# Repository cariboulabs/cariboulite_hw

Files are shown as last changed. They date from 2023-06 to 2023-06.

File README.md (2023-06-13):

# CaribouLite
CaribouLite is an affordable, educational, open-source SDR evaluation platform and a HAT for the Raspberry-Pi family of boards (40-pin versions only). It is built for makers, hackers, and researchers and was designed to complement the current SDR (Software Defined Radio) eco-systems offering with a scalable, standalone dual-channel software-defined radio.

<table>
  <tr>
    <td>Open source hardware association certificate</td>
    <td>This project has been certified by OSHWA</td>
  </tr>
</table>

<table>
  <tr>
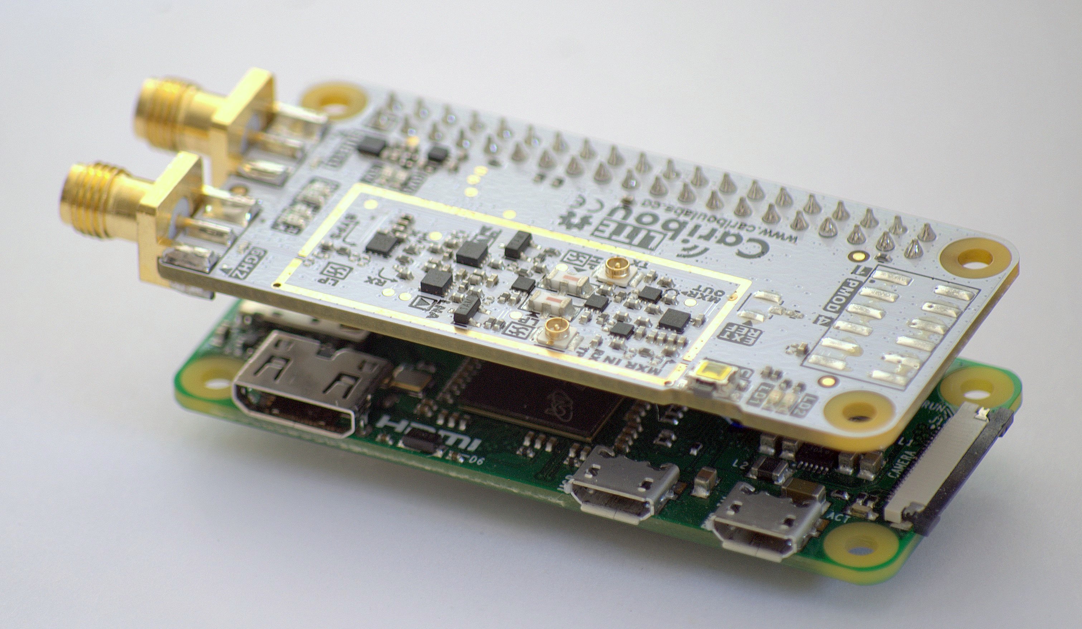
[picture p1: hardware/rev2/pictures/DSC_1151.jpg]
CaribouLite R2
    <td></td>
  </tr>
  <tr>
    <td>CaribouLite R2.5 SDR mounted on a RPI-Zero</td>
  </tr>
</table>

# Getting Started & Installation
Use the following steps to install the CaribouLite on your choice of RPI board
1. Mount the CaribouLite on a **un-powered** RPI device using the 40-pin header.
2. Power the RPI device, wait for it to finish boot sequence.
3. Clone this repository into a local directory of your choise (in this case `~/projects`)
```
mkdir ~/projects
cd ~/projects
git clone https://github.com/cariboulabs/cariboulite
cd cariboulite
```
4. Use the following setup command (**note: don't `sudo` it**):
    ```
    install.sh
    ```

The setup script **requires internet connection** and it follows the following automatic steps:
1. **Dependencies** installation (apt)
2. **Soapy API tools installation** (SoapySDR and SoapyRemote) - only if they are not currently present in the system. Installation from code.
3. **Internal dependencies installation**
   1. Utilities and tools
   2. IIR DSP library
   3. SMI stream device module (kernel object) blob generation
4. **Main software** and SoapyAPI compilation and installation
5. **Raspberry PI configuration** verification. Note - the installer doesn't not actively change the RPI's configuration to fit to CaribouLite. It just checks the `/boot/config.txt` configuration file and raises warning when problem is detected. Then the user shall need to adjust the parameters accordingly.

Note: the user will be requested to enter their password during the installation process.

## Installation Troubleshooting
1. **Modules**: Both the `spi` and `arm-i2c` dtoverlays should be disabled to run CaribouLite properly. The `libcariboulite` doen't use them. It uses direct access to `/dev/mem` to expose these peripherals (through the `pigpio` library).
The interfaces can be disabled (or enabled back whenever needed) by either directly editing the `/dev/config.txt` file or by using the `sudo raspi-config` command. The latter is the preferred choice as it is straight forward, less error prone and it works on all RaspberryPi's OS distributions (including DragonOS).
If the direct editing path has been chosen (`/boot/config.txt`), the following lines
should be commented out:
`#dtparam=spi=on`
`#dtparam=i2c_arm=on`

2. **Kernel headers** - `libcariboulite` loads a custom kernel module (`smi_stream_dev`) during startup. The kernel module sources are location in : **`/software/libcariboulite/caribou_smi/kernel`**. Recompilation of these .ko obejcts is needed whenever software is pulled. This requires currently to have the local host system to have the kernel headers installed. In addition, upgrading the kernel will require recompilation with the updated kernel headers. Once the `smi_stream_dev` is listed inside the main kernel tree, this process will become redundant.

3. **sudo**ing - Currently hardware is accessed through the PIGPIO library. It should be given a root access to control the low level interfaces through the `/dev/mem` device. The relevant part of the software that is concerned in this matter is the "io_utils" sub-module. Once this module is re-designed to access the hardware through the "gpiomem" and "spidev" modules, this restrictions shall be mitigated (by the definitions of `udev` rules).
So currently, sudo'ing is needed whenever CaribouLite is accessed (including sudo'ing python...).

To compile the API library and SoapySDR API from code please click [here](/software/libcariboulite/README.md)

# SMI Interface

Unlike many other HAT projects, CaribouLite utilizes the **SMI** (Secondary Memory Interface) present on all the 40-pin RPI versions. This interface is not thoroughly documented by both Raspberry-Pi documentation and Broadcomm's reference manuals. An amazing work done by [Lean2](https://iosoft.blog/2020/07/16/raspberry-pi-smi/) (code in [git repo](https://github.com/jbentham/rpi)) in hacking this interface has contributed to CaribouLite's technical feasibility. A deeper overview of the interface is provided by G.J. Van Loo, 2017 [Secondary_Memory_Interface.pdf](docs/smi/Secondary%20Memory%20Interface.pdf). The SMI interface allows exchanging up to ~500 Mbit/s (depending on the FPGA, data-bus width, etc.) between the RPI and the HAT, and yet, the results vary between the different versions of RPI. The results further depend on the specific RPI version's DMA speeds.

The SMI interface can be accessed from the user space Linux applications as shown in [Lean2](https://iosoft.blog/2020/07/16/raspberry-pi-smi/), but Broadcomm also provided a neat minimal charachter device interface in the `/dev` directory using the `open`, `close`, `write`, `read`, and `ioctl` system calls. More on this interesting interface in the [designated readme file](software/libcariboulite/src/caribou_smi/index.md). This device driver needs to be loaded using `modprobe`.

More information on this interface can be found [here (HW side)](docs/smi/README.md) and [here (SW side)](software/libcariboulite/src/caribou_smi/README.md).

<table>
  <tr>
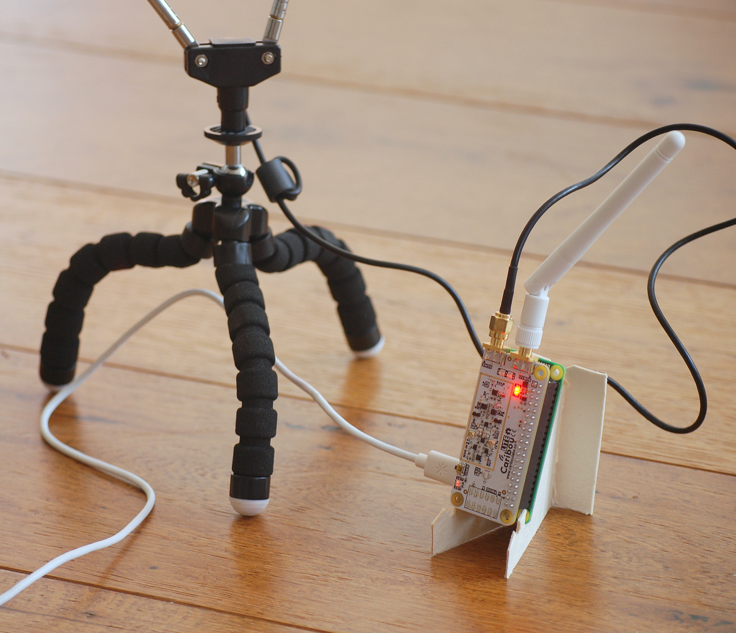
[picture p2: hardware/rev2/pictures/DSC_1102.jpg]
    <td></td>
  </tr>
  <tr>
    <td>Cariboulite /w RPI Zero, two channels occupied</td>
  </tr>
</table>

# Hardware Revisions
The board first prototyping (**Red**) revision ([REV1](hardware/rev1)) has been produced and tested to meet our vision on the board's capabilities. This revision was used to test its RF parts, the digital parts, and to develop its firmware and software support over the RPI.

<table>
  <tr>
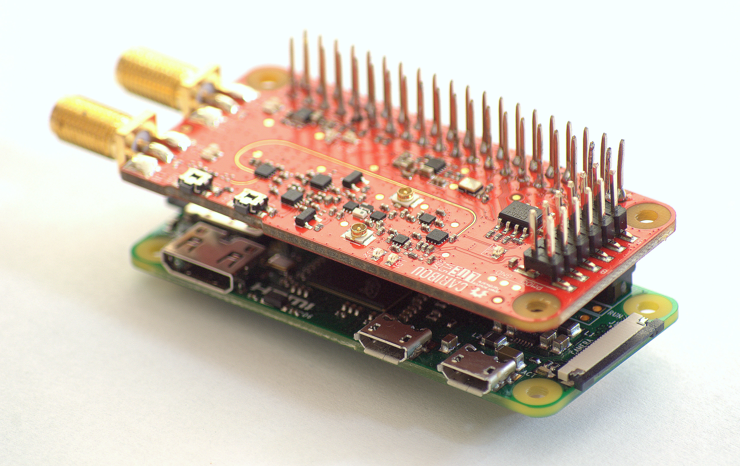
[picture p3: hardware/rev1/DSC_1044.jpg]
CaribouLite R1
    <td></td>
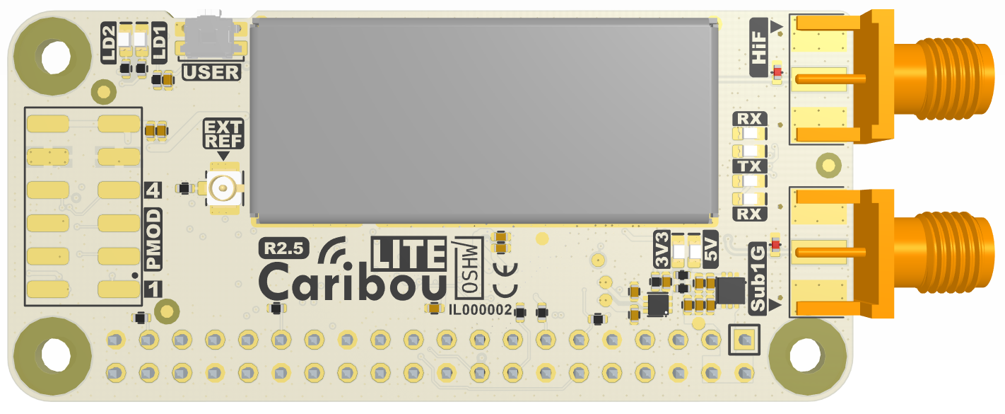
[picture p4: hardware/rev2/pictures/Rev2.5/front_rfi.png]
CaribouLite Connectors
    <td></td>
  </tr>
  <tr>
    <td>CaribouLite Rev1 - the prototype version</td>
    <td>CaribouLite Rev2.5 - Production Revision</td>
  </tr>
</table>

The second revision ([REV2](hardware/rev2)) - **White** - was then designed to further refine the design as described below:
1. Image rejection filtering improvement - U10 and U12 (HPF & LPF) - have been replaced by integrated LTCC filters by MiniCircuits with much better out-of-band rejection than the former ones.
2. Removing FPGA flash - redundant given the fact that the the RPI configures the FPGA in <1sec over SPI. Even if we have a whole library of custom made FPGA firmware files, switching between them is as simple and fast as a single linux command.
3. Board layout improvements and overlays (silkscreen) beautification (including logo).
4. A single system level 3.3V power (while the FPGA still receives 2.5V and 1.2V for its core). A linear regulator (rather than a switching DC-DC) was used to reduce conducted (power and ground) noise levels.
5. Top and bottom EMI sheilding option - the EMI/RFI shield design models are provided in the [3d directory](hardware/rev2/3d/)
6. More detailed changes in the [schematics](hardware/rev2/schematics/cariboulite_r2_sch.PDF).

In summary, in CaribouLite-Rev2.5 PCB design has been thoroughly re-thought to meet its educational needs with performance in mind. The RF path has been annotated with icons to ease the orientation in the schematics sheets, friendly silk writing was added describing system's components by their functionality rather than logical descriptors, and more.

<table>
  <tr>
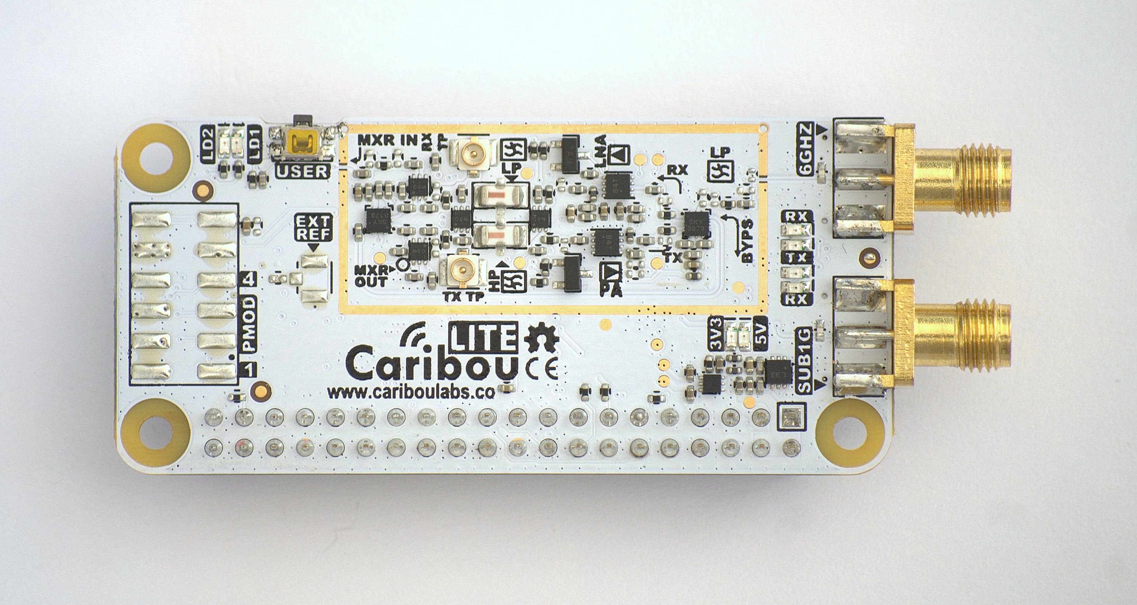
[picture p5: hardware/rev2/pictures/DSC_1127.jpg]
    <td></td>
  </tr>
  <tr>
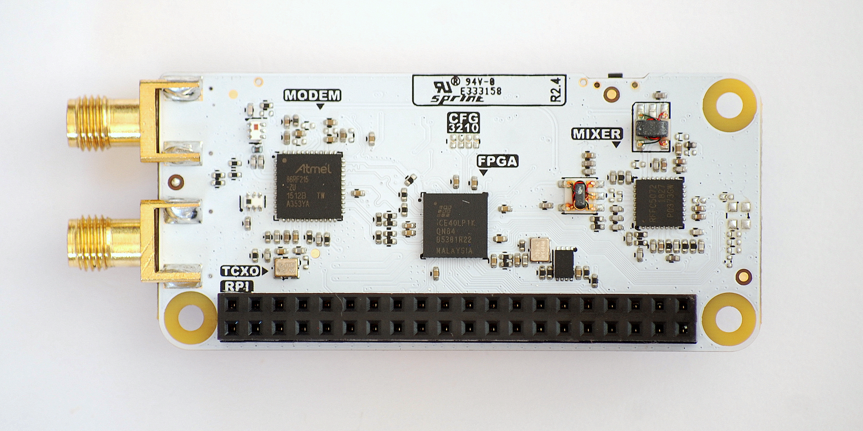
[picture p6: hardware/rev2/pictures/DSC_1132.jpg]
    <td></td>
  </tr>
  <tr>
    <td>Top and Bottom views of CaribouLite <b>Rev2.4</b> (pre-production)</td>
  </tr>
</table>

<table>
  <tr>
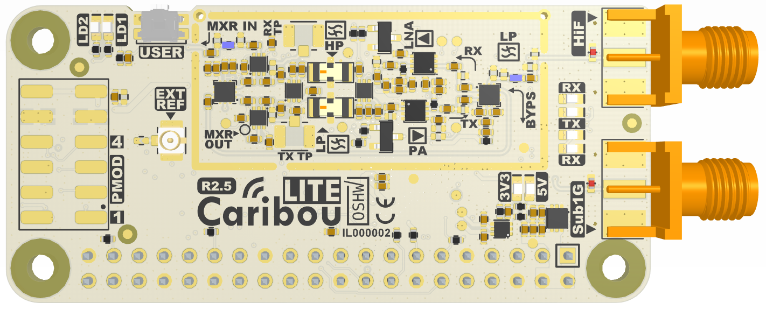
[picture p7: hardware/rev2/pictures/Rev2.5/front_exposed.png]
    <td></td>
    <td>Top View</td>
  </tr>
  <tr>
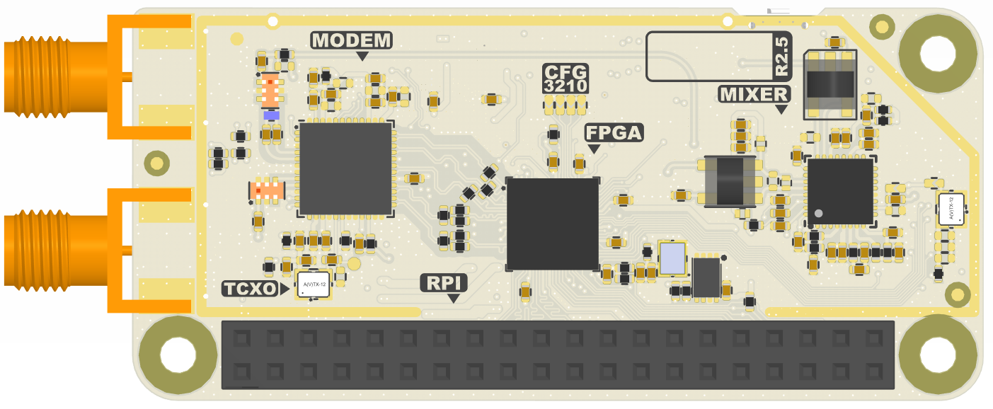
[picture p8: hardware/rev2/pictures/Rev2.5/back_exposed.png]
    <td></td>
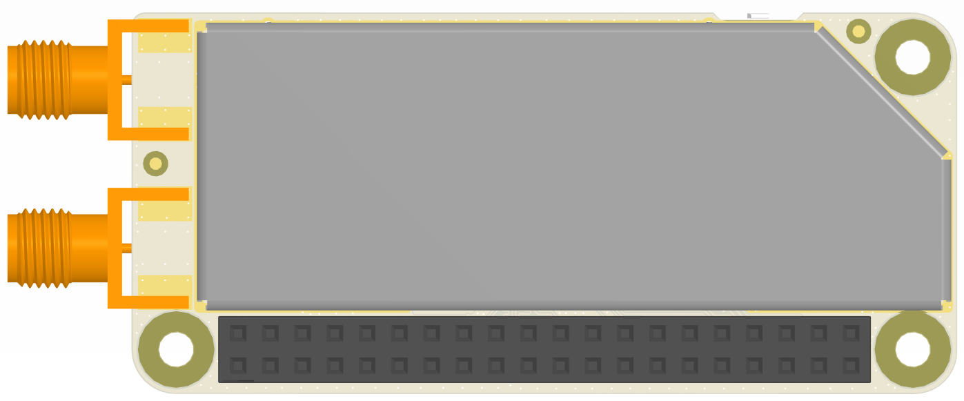
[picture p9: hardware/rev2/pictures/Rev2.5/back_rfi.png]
  <td></td>
  </tr>
  <tr>
    <td>Top and Bottom views of CaribouLite <b>Rev2.5</b></td>
    <td>Top and Bottom views of CaribouLite <b>Rev2.5</b> with EMI/RFI shields</td>
  </tr>
</table>

# Specifications

<B>RF Channels:</B>
- Sub-1GHz: 389.5-510 MHz / 779-1020 MHz
- Wide tuning channel: 30 MHz - 6 GHz (excluding 2398.5-2400 MHz and 2483.5-2485 MHz)

<table>
  <tr>
    <td>spectra</td>
  </tr>
  <tr>
    <td style="text-align:center">Applicable spectra, S1G - sub-1GHz, WB - Wide tuning channel</td>
  </tr>
</table>
<B>Note</B>:
The gaps are defined by the design constraints of the system and may not exist in real-life hardware. Actual modem synthesizer outputs test show wider margins at room temperature than those written in the datatsheet, but, as noted by Microchip, performance may suffer.

<B>FPGA specifications:</B>
- 160 LABs / CLBs
- 1280 Logic Elements / Cells
- 65536 Total RAM bits
- 67 I/Os, Temp: -40-100 degC

<B>Applicable RPI models</B>: RPI_1(B+/A+), RPI_2B, RPI_Zero(Zero/W/WH), RPI_3(B/A+/B+), RPI_4B

Parameter                  |  Sub-1GHz                    | Wide Tuning Channel
---------------------------|------------------------------|------------------------------------------------------------------
Frequency tuner range      | 389.5-510 MHz / 779-1020 MHz | 30 MHz - 6 GHz (excluding 2398.5-2400 MHz and 2483.5-2485 MHz)
Sample rate (ADC / DAC)    | 4 MSPS                       | 4 MSPS
Analog bandwidth (Rx / Tx) | 2.5 MHz                      | 2.5 MHz
Max Transmit power         | 14 dBm                       | >10 dBm @ 30-2400 MHz, >5 dBm @ 2400-6000 MHz
Receive noise figure       | <5 dB                      | <6 dB @ 30-3500 MHz, <8 dB @ 3500-6000 MHz

<B>Note</B>:
(1) Feature comparison table with other SDR devices will be published shortly
(2) Some of the above specifications are simulated rather than tested
(3) Analog bandwidth controlled by the modem
(4) The ISM version of the board doesn't contain the wide-range of frequencies (30-6000 MHz) and contains the native capabilities of the Modem IC.

# Disclaimer
CaribouLite is a test equipment for RF systems. You are responsible for using your CaribouLite legally.

Definitions: THE SUBJECT CONTENT: all files, software, instructions, information, ideas and knowledge located in this git repository.

No Warranty: THE SUBJECT CONTENTS ARE PROVIDED "AS IS" WITHOUT ANY WARRANTY OF ANY KIND, EITHER EXPRESSED, IMPLIED, OR STATUTORY, INCLUDING, BUT NOT LIMITED TO, ANY WARRANTY THAT THE SUBJECT CONTENTS WILL CONFORM TO SPECIFICATIONS, ANY IMPLIED WARRANTIES OF MERCHANTABILITY, FITNESS FOR A PARTICULAR PURPOSE, OR FREEDOM FROM INFRINGEMENT, ANY WARRANTY THAT THE SUBJECT CONTENTS WILL BE ERROR FREE, OR ANY WARRANTY THAT DOCUMENTATION, IF PROVIDED, WILL CONFORM TO THE SUBJECT CONTENTS. FURTHER, THE REPOSITORY OWNERS AND CONTRIBUTORS DISCLAIM ALL WARRANTIES AND LIABILITIES REGARDING THIRD-PARTY SOFTWARE, IF PRESENT IN THE ORIGINAL SOFTWARE, AND DISTRIBUTE IT "AS IS."

Waiver and Indemnity: RECIPIENT AGREES TO WAIVE ANY AND ALL CLAIMS AGAINST THE REPOSITORY OWNERS AND CONTRIBUTORS, THEIR CONTRACTORS AND SUBCONTRACTORS, AS WELL AS ANY PRIOR RECIPIENT. IF RECIPIENT'S USE OF THE SUBJECT CONTENTS RESULTS IN ANY LIABILITIES, DEMANDS, DAMAGES, EXPENSES OR LOSSES ARISING FROM SUCH USE, INCLUDING ANY DAMAGES FROM PRODUCTS BASED ON, OR RESULTING FROM, RECIPIENT'S USE OF THE SUBJECT CONTENTS, RECIPIENT SHALL INDEMNIFY AND HOLD HARMLESS THE REPOSITORY OWNERS AND CONTRIBUTORS, THEIR CONTRACTORS AND SUBCONTRACTORS, AS WELL AS ANY PRIOR RECIPIENT, TO THE EXTENT PERMITTED BY LAW.

# License
<br />This work is licensed under a <a rel="license" href="http://creativecommons.org/licenses/by-sa/4.0/">Creative Commons Attribution-ShareAlike 4.0 International License</a>.

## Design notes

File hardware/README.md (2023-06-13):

# CaribouLite Hardware

## CaribouLite Hardware Revisions

CaribouLite board has two revisions:

1. Rev1: A prototyping revision (the red board).
2. Rev2: Production revision (currently R2.5 is the production-grade version).
   1. Rev2_r2.4: pre-production revision

This documentation shall cover the production-grade board (rev2).

## System Diagram

<table>
  <tr>
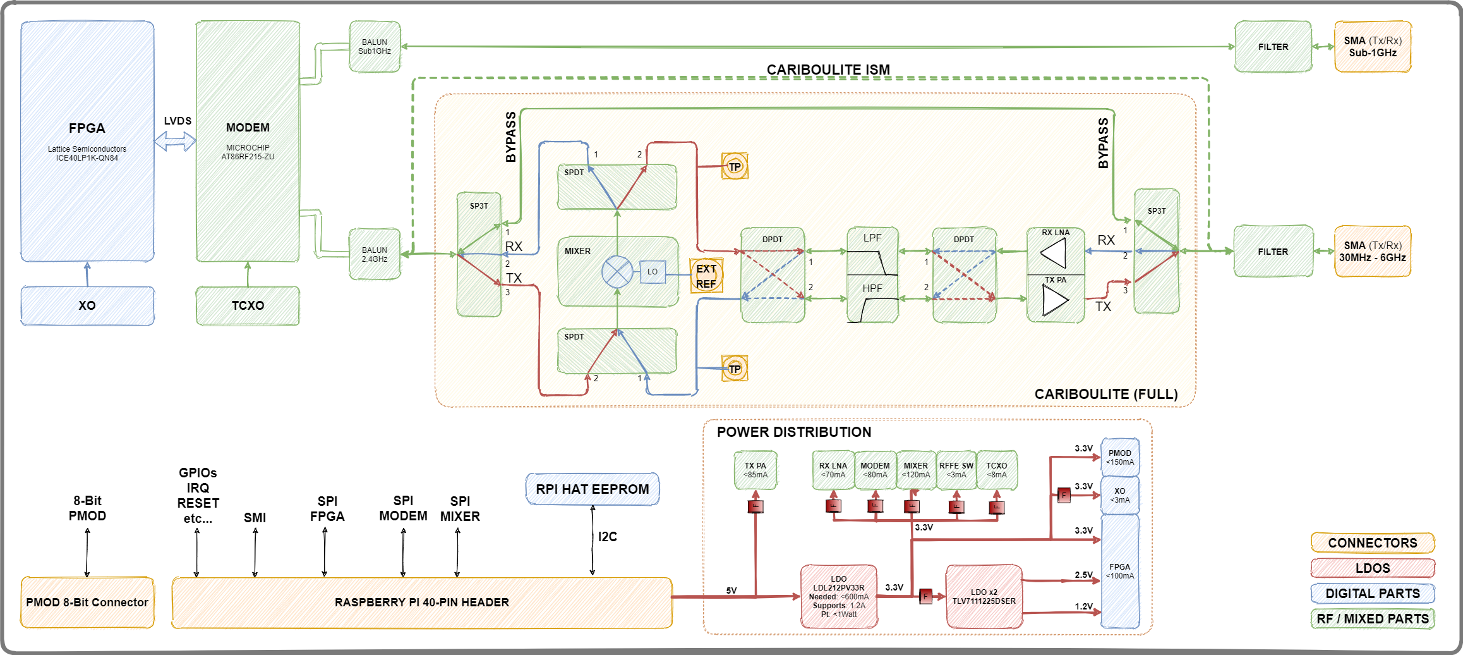
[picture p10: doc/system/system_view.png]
Top View
    <td></td>
  </tr>
  <tr>
    <td>CaribouLite SDR System Diagram</td>
  </tr>
</table>

The **RF chart** in the 6GHz channel was inspired by the **RF front-end of HackRF-One by @greatscottgadgets** (an amazing ground breaking work still relevant today) with a few changes:
1. Usage of DPDTs instead of SPDTs in the filter-bank section. Usage of less switches in general.
2. Using higher attenuation stop-band filtering for a slightly better image rejection.
3. Mixer balun's according according to the requirements of the mixer IC.
4. LNA / PA slight improvements.

Possibilities exist to replace the 6GHz by a other types of components by Qorvo that are pin2pin compatible with the RFFC5072.

### Power Distribution

To simplify the board and its interfacing to the Raspberry Pi computer, all components on board operate with 3.3V. The FPGA further requires also 1.2V and 2.5V voltages. Two LDO components have been used to derive these voltages from the RPI 5V output voltage.

The usage of LDOs provides high level of voltage isolation, low emitted noise, and design simplicity. The downside of such choice it the dissipated heat from the LDOs. This heat is controlled by providing descent heat sinking to the board through the power planes and adjacent metallic elements (i.g. connectors).

The power distribution provides high frequency isolation of the RF components from the digital components (memory, RPI and FPGA) at frequencies lower than 10 MHz. Above 100 MHz additional isolation is provided by using ferrite beads with high impedance (>500 Ohms) at 100MHz. A set of filtering bypass capacitors have been chosen to further suppress noise generated by components on their power lines at mid-range frequencies (10 to 100 MHz) - the set contains 1nF, 100 nF and 4.7uF capacitors bypassing power and data lines effective at the said frequency ranges.

### RPI HAT EEPROM

An I2C EEPROM device is assembled on CaribouLite to support for the requirements of RPI HATs as described in [RPI HAT Requirements](https://github.com/raspberrypi/hats).
Production application helps to perform the EEPROM configuration process (coming soon)

### Clocking

The FPGA is externally clocked by a crystal oscillator of 125MHz located in the bottom side of the board.
Clocking the FPGA from the RPI GPCLK (GPIO4 / GPCLK0 / SMI_SA1) is also possible but not recommanded as it may cause substantial increase in the board EMI. For that reason, the GPCLK option is possible but not used in the mainline hardware version. Hacking the possibility to clock from the RPI is a good idea though.

The MODEM (AT86RF215) is clocked from a 26MHz TCXO (bottom layer). This device provides a stable and low phase noise clock reference to the receivers and transmitters within the IC. The MODEM further outputs a buffered version of the input clock (typically 26MHz, but other possibilities exist as well), to the MIXER input. A capacitor divider circuit adapts the LVCMOS output from the MODEM to the input levels of the MIXER.

The MIXER can also be clocked from a separate dedicated TCXO (not assembled), or an external coherent clock source.
<table>
  <tr>
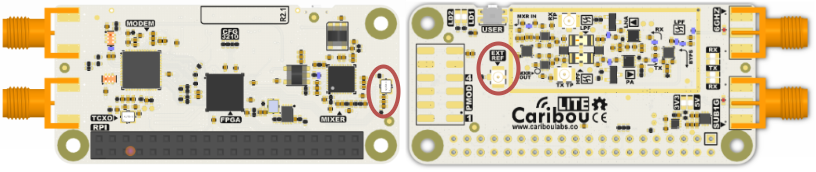
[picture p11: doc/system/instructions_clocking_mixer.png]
    <td></td>
  </tr>
  <tr>
    <td>MIXER clocking options, other than the default MODEM provided reference clock</td>
  </tr>
</table>
To enable the above clocking schemes, the MODEM clock input jumper should be cut, and the appropriate jumpers need to be shorted. Consult the schematics to learn more.

### PMOD Connector

Coming soon:

* Synchronization
* GPS PPS Signaling
* Peripherals
* Maximal current

### FPGA and LVDS

Coming soon - LVDS calculations

### Calibrations & Testing

Coming soon

## License

<br />This work is licensed under a <a rel="license" href="http://creativecommons.org/licenses/by/4.0/">Creative Commons Attribution 4.0 International License</a>.

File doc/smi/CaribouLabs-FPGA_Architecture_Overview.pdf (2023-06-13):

# CaribouLite FPGA / SMI

# - Overview - Architecture - Firmware Software - Firmware top level - SMI I/F

Creative Commons Attribution-ShareAlike 4.0 International License. (http://creativecommons.org/licenses/by-sa/4.0/)

# Portable SDR?

# We wanted to make a portable RF board that connects to an existing compute unit

# >70% of the RF board (the front-end) should be RF components!

RF

# (SDR Front-End)

# A popular Tiny computer (SDR Baseband)

# Some “communication”

# Small and self-contained SDR

# Portable

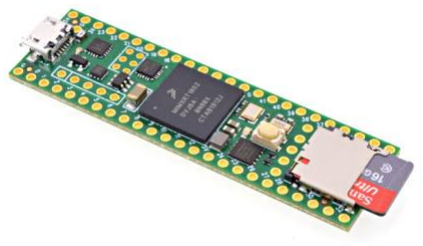
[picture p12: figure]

# SDR?

# The platform problem

# - We want to focus on RF, not Compute - So, which is the best platform?

TEENSY 4.1 | Raspberry Pi | Jetson Nano

# +++ Cheap ++ Popular + NXP-FlexIO

# --- Performance --- No Linux

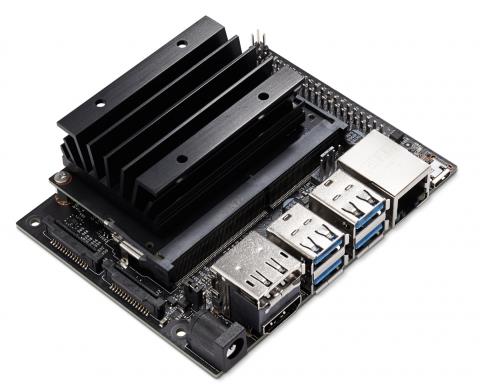
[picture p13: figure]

# +++ Performance ++ Popular

+ AI

# - Expensive -- I/Q Interface?

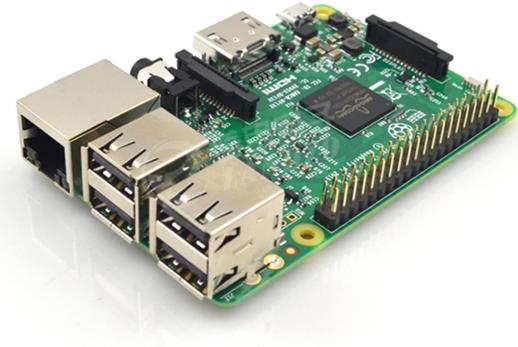
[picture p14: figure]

# ++ Performance +++ Popular (community) +++ Cheap - Affordable

# - I/Q Interface?

# SMI

# Top Structure

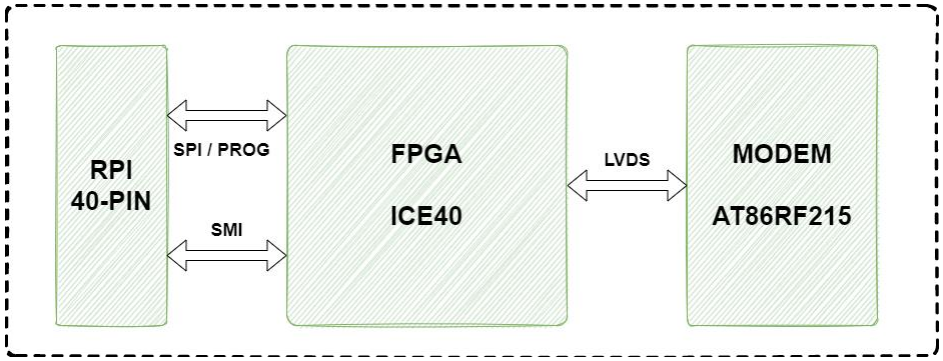
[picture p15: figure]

# - FPGA mediates between LVDS and SMI - SPI – controlling FPGA functionality - FPGA programming – done by RPI (Lattice SPI)

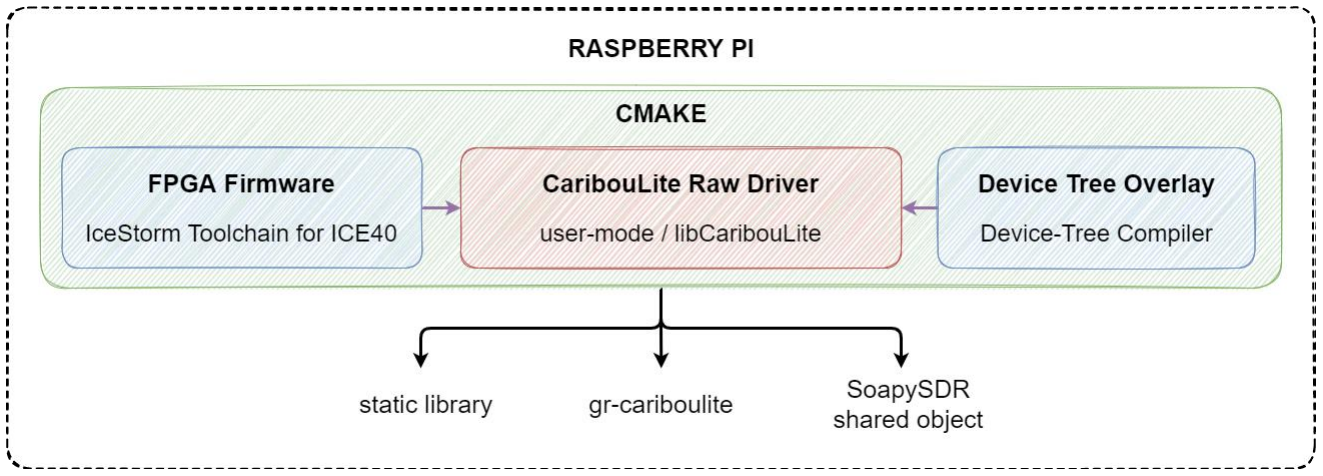
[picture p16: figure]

# Firmware

# Software

# Integration

# - Verilog – Yosys + NextPNR ➔ code blob in C/C++ - Device tree – DTC ➔ code blob in C/C++ - One CMAKE project ➔ SoapySDR, GnuRadio, static-lib

# - All inside Raspberry Pi

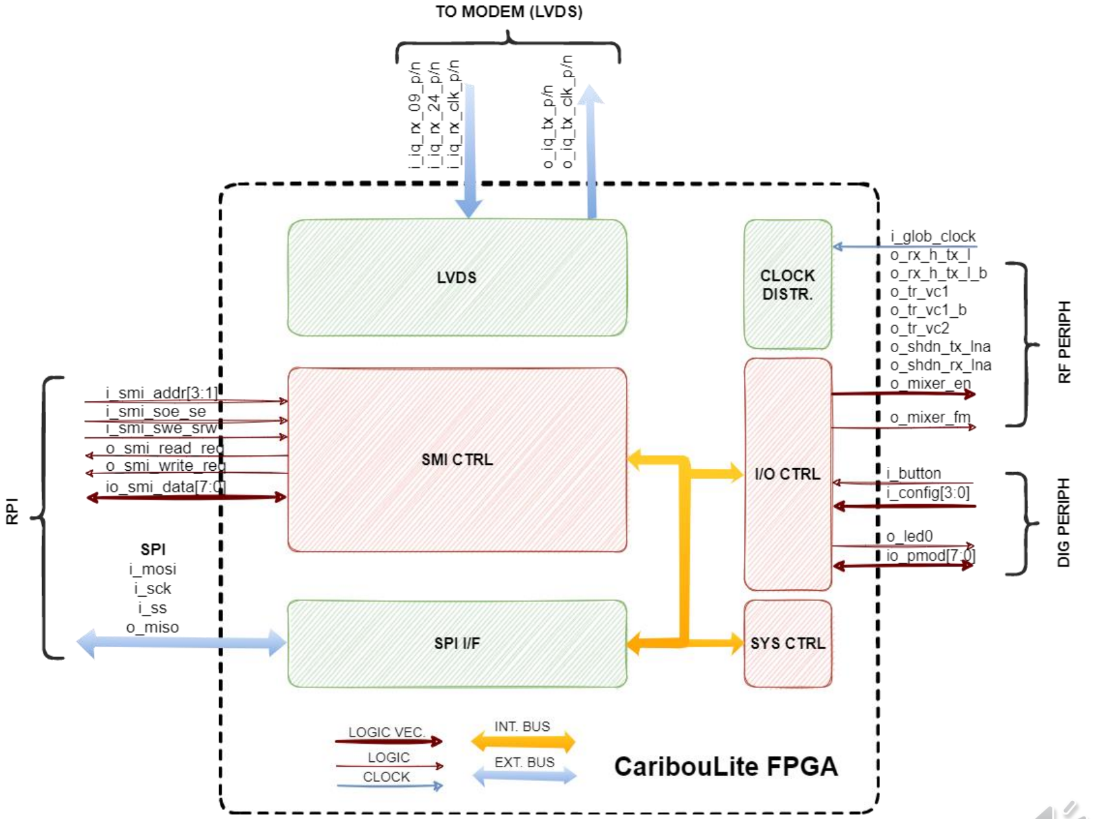
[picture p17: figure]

# Firmware Top-Level

# - Three controllers with bus - Sys-Ctrl - I/O-Ctrl - SMI-Ctrl

# - SPI I/F controlling all

# - Digital clock: 125 MHz

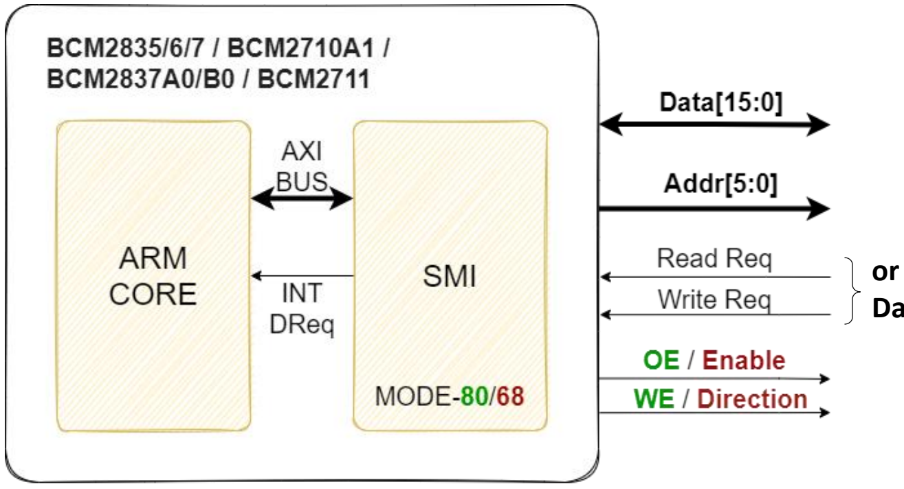
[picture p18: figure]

# SMI Signals

# - Two operation modes - Mode-80 - Mode-68

# - CaribouLite uses: - 8-bit data (out of 16) - 3-bit address (out of 6)

- Read-Req. / Write-Req.

# - Mode-80 signaling

Thank you,
- van Loo et.al., 2017, Secondary Memory Interface (SMI)
- Lean2, 2020, https://iosoft.blog/2020/07/16/raspberry-pi-smi/

# Data16/17

# SMI

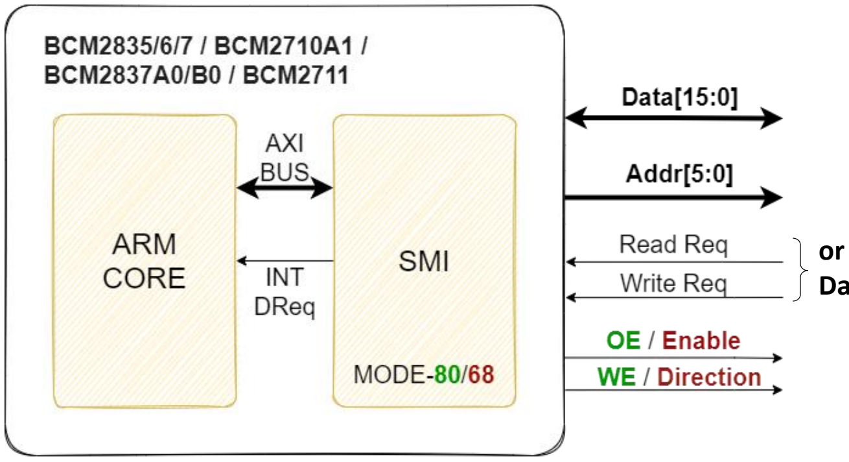
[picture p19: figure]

# Performance

## - Standard configuration:

SOE strobe: Tsoe,strobe = 2 cc

## Bus Freq.: Fbus = 125 MHz Data Len.: Ldata = 8bit Potential:

S = Fbus/(Tsoe,strobe+1) ∙ Ldata

⇒ S =

125
3

## ∗ 8 = 333 Mbit/sec

## - BUT: 1. Read and write share Data[7:0] 2. Channel config takes time (address) 3. We use only 8-bit data! 4. Next => 16-bit data

Thank you,

### - van Loo et.al., 2017, Secondary Memory Interface (SMI) - Lean2, 2020, https://iosoft.blog/2020/07/16/raspberry-pi-smi/

# Data16/17

# SMI Performance

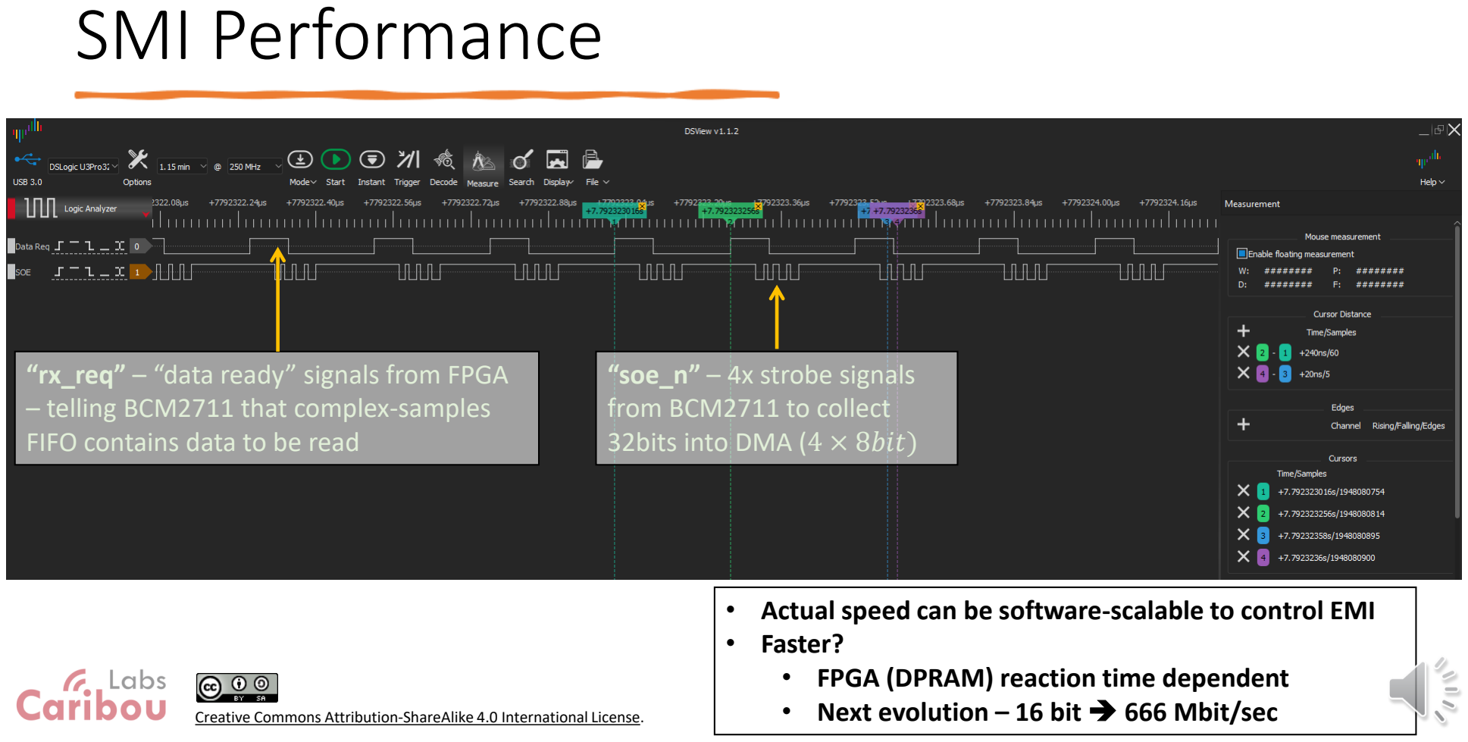
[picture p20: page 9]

# “rx_req” – “data ready” signals from FPGA – telling BCM2711 that complex-samples FIFO contains data to be read

# “soe_n” – 4x strobe signals from BCM2711 to collect 32bits into DMA (4 × 8bit)

# - Actual speed can be software-scalable to control EMI - Faster? - FPGA (DPRAM) reaction time dependent - Next evolution – 16 bit ➔ 666 Mbit/sec

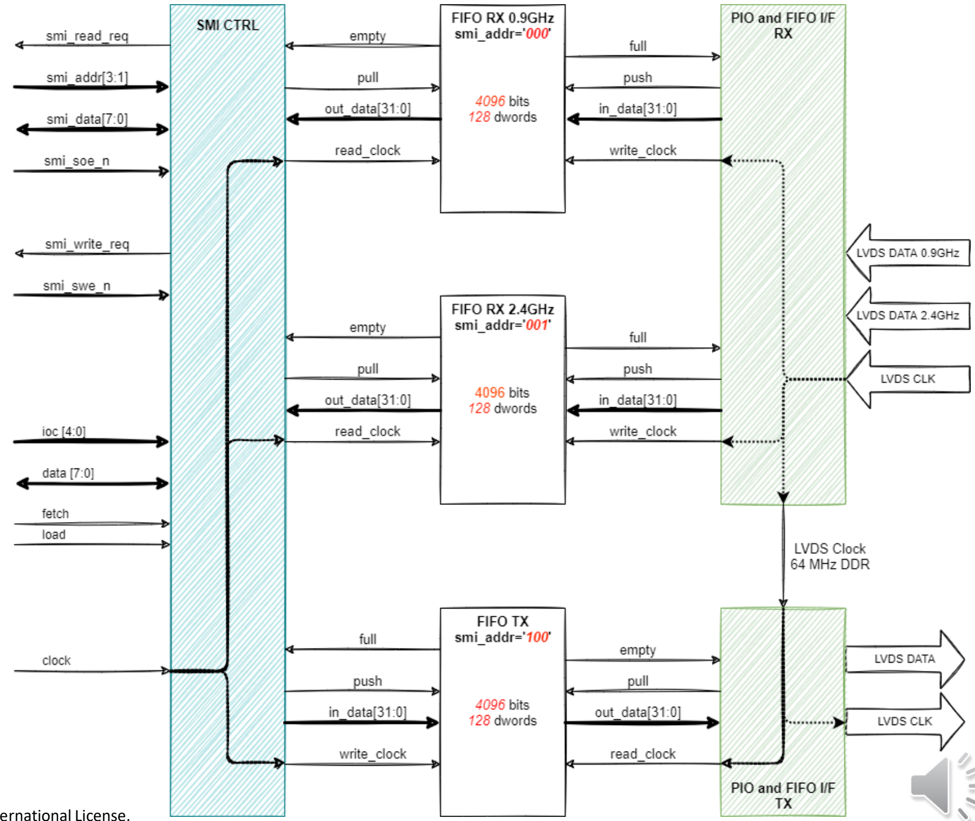
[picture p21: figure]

# Data-Path

# - Dual-port RAM

- Complex-Numbers queue.

# - Back pressure

# - Two clock regions – - LVDS from modem - Digital from RPI side

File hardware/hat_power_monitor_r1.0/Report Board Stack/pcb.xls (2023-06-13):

Board Stack Report
Stack Up |  | Layer Stack
Layer | Board Layer Stack | Name | Material | Thickness | Constant
1 |  | Top Paste
2 |  | Top Overlay
3 |  | Top Solder | Solder Resist | 0.40mil | 3.5
4 |  | Top Layer | Copper | 1.40mil
5 |  | Dielectric 1 | FR-4 | 55.00mil | 4.8
6 |  | Bottom Layer | Copper | 1.40mil
7 |  | Bottom Solder | Solder Resist | 0.40mil | 3.5
8 |  | Bottom Overlay
9 |  | Bottom Paste
 | Height : 58.60mil

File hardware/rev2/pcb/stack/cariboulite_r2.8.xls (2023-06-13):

Board Stack Report
Stack Up |  |  |  |  |  | Layer Stack
Layer | Board Layer Stack | Board Layer Stack | Board Layer Stack | Board Layer Stack | Board Layer Stack | Name | Material | Thickness | Constant
1 |  |  |  |  |  | Top Paste
2 |  |  |  |  |  | Top Overlay
3 |  |  |  |  |  | Top Solder | White | 1.00mil | 4
4 |  |  |  |  |  | Component Side | Copper | 1.38mil
5 |  |  |  |  |  | Dielectric 1 | PrePreg | 4.33mil | 4.3
6 |  |  |  |  |  | Layer 1 | Copper | 1.38mil
7 |  |  |  |  |  | Dielectric 7 | FR-4 | 47.24mil | 4.3
8 |  |  |  |  |  | Layer 2 | Copper | 1.38mil
9 |  |  |  |  |  | Dielectric 2 | PrePreg | 4.33mil | 4.3
10 |  |  |  |  |  | Solder Side | Copper | 1.38mil
11 |  |  |  |  |  | Bottom Solder | White | 1.00mil | 4
12 |  |  |  |  |  | Bottom Overlay
13 |  |  |  |  |  | Bottom Paste
 | Height : 63.42mil | Height : 63.42mil | Height : 63.42mil | Height : 63.42mil | Height : 63.42mil

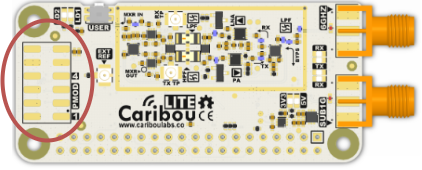
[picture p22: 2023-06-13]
hardware/rev2/pictures/focus_pmod.png

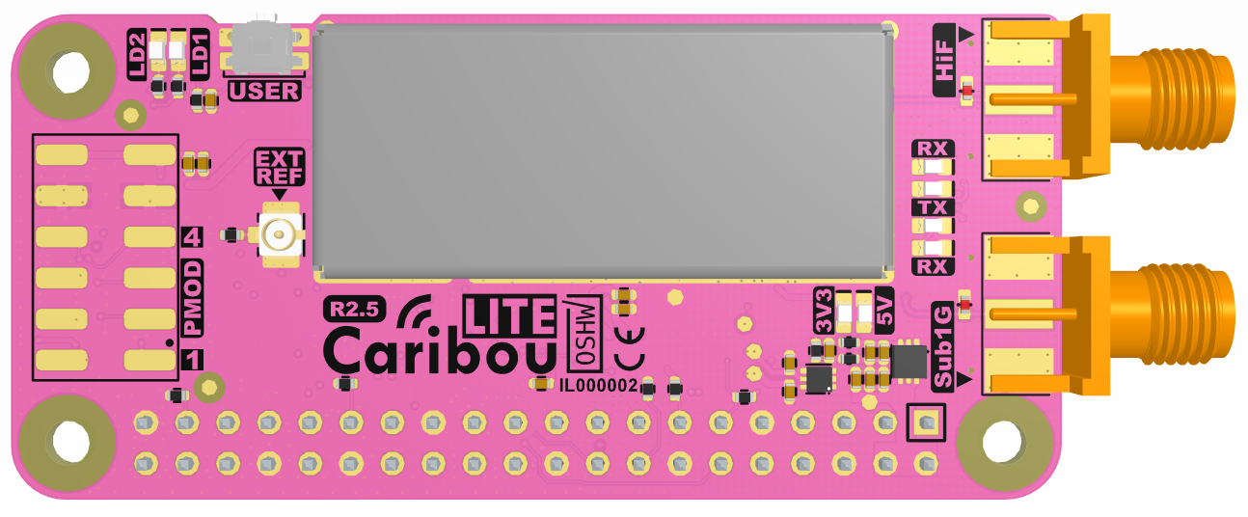
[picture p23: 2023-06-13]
hardware/rev2/pictures/Rev2.5/colors_pink.png

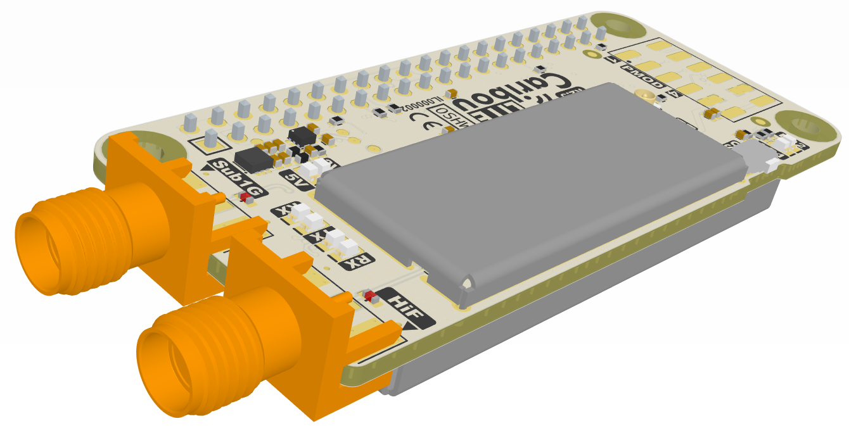
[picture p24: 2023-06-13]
hardware/rev2/pictures/Rev2.5/side_rfi.png

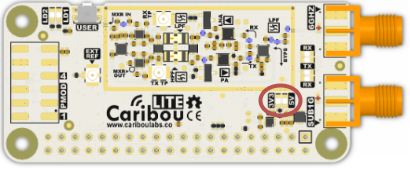
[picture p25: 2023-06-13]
hardware/rev2/pictures/focus_power_leds.png

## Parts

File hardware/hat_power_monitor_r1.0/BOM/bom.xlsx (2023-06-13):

Line # | Designator | Manu. P/N | Quantity | Value | Description | Footprint | Name
13 | U3 | AP22652W6-7 | 1 |  | Power Switch ICs - Power Distribution 1-Ch Precision Curr-Limit Load SW | SOT95P280X145-6N | AP22652W6-7
12 | U2 | AVR32DA32T-E/RXB | 1 |  | 8-bit Microcontrollers - MCU 32 KB,32-pin,125C,VQFN | QFN50P500X500X90_HS-33N | AVR32DA32T-E/RXB
11 | U1 | INA181A4IDBVT | 1 |  | 26V, bi-directional, 350kHz current sense amplifier 6-SOT-23 -40 to 125 | SOT95P280X145-6N | INA181A4IDBVR
10 | R5, R7, R8, R11, R12 | CRCW0402470RFKEDC | 5 | 470 | Thick Film Resistors - SMD 1/16watt 470ohms 1% | PANASONIC 0402 | 470
9 | R4 | ERJ-6CWFR010V | 1 | 10 mOhm | Resistor | RES_ERJ6CW | 10 mOhm
8 | R1, R2, R3, R9, R10, R13, R14, R15, R16 | CRCW040210K0FKEDC | 9 | 10k | Thick Film Resistors - SMD 1/20watt 10Kohms 1% 200ppm | PANASONIC 0402 | 10k
7 | J2 | M20-9770446 | 1 |  | Header Male 4X1 | M20-9770446 | M20-9770446
6 | J1 | M20-9720346 | 1 |  | Header Male 2X3 | M20-9720346 | M20-9720346
5 | D1, D2, D3, D4 | LTST-C190KRKT | 4 |  | Red 631nm LED Indication - Discrete 2V 0603 | LEDC1608X35N | LTST-C190KRKT
4 | C7 | T495X476M035ATE230 | 1 | 47u | Tantalum Capacitors - Solid SMD 35V 47uF 2917 20% ESR=230mOhms | CAPMP7343X28N | 47u
3 | C4, C8, C9 | CL05A106MP6NUN8 | 3 | 10u | Multilayer Ceramic Capacitors MLCC - SMD/SMT 10uF+/-20% 10V X5R 1 0402 | MURATA 0402 | 10u
2 | C1, C2, C3, C5, C6 | GRT155R71H104KE01D | 5 | 100n | Multilayer Ceramic Capacitors MLCC - SMD/SMT 50V 0.1uF X7R 0402 10% | MURATA 0402 | 100n
1 |  | 95278-102-40LF, SSM-120-L-DV | 1 |  | Raspberry Pi back to back footprint | rpi_4_SEP | RaspberryPi_SEP

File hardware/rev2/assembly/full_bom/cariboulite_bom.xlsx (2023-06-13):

Designator | Manu. P/N | Quantity | VALUE | Description | Footprint | Comment
C1, C26, C33, C66, C79, C121, C127 | GRJ155R61A475ME11J | 7 | 4.7u | Multilayer Ceramic Capacitors MLCC - SMD/SMT 0402 MLCC X5R 4.7 uF +/ -20% 10V | MURATA 0402 | 4.7u
C3, C14, C21, C23, C27, C28, C30 | LMK105BJ105MVHF | 7 | 1u | Multilayer Ceramic Capacitors MLCC - SMD/SMT 0402 10VDC 1uF 20% X5R | MURATA 0402 | 1u
C5, C7, C9, C10, C17, C34, C36, C65, C68, C69, C71, C72, C73, C74, C81, C86, C89, C119, C120 | 0402YD104KAT2A | 19 | 100n | Multilayer Ceramic Capacitors MLCC - SMD/SMT 16V .1uF X5R 0402 10% | MURATA 0402 | 100n
C11 | 0402N2R2B500CT | 1 | 2.2p | Multilayer Ceramic Capacitors MLCC - SMD/SMT, 0402 2.2pF +-0.1% 50V | MURATA 0402 | 2.2p
C12, C20 | 0402N1R8B500CT | 2 | 1.8p | Multilayer Ceramic Capacitors MLCC - SMD/SMT, 0402 1.8pF +-0.1% 50V | MURATA 0402 | 1.8p
C13, C15, C35, C37, C38, C41, C42, C43, C47, C48, C49, C50, C51, C54, C55, C56, C57, C60, C61, C62, C64, C70, C75, C77, C78, C82, C83, C84, C85, C90, C93, C95, C96, C99, C129, C130, C131, C132 | GRM1555C2A102JE01D | 38 | 1n | Multilayer Ceramic Capacitors MLCC 1000pF ±5% 100V C0G 0402 | MURATA 0402 | 1n
C16, C24, C25, C39, C63, C87, C103, C105, C106, C107, C112, C116, C118, C125, C126 | C0402C330J5GAC | 15 | 33p | Multilayer Ceramic Capacitors MLCC - SMD/SMT 0402 50V 33pF C0G 0402 5% | MURATA 0402 | 33p
C19 | GCM1555C1HR80WA16D | 1 | 0.8p | Multilayer Ceramic Capacitors MLCC - SMD/SMT 0402 0pF 50volts C0G, 0.8pF | MURATA 0402 | 0.8p
C22 | 0402N150J500CT | 1 | 15p | Multilayer Ceramic Capacitors MLCC - SMD/SMT 0402 15pF 50volts, C0G | MURATA 0402 | 15p
C31, C32, C67, C102, C111, C115, C117 | GRM1555C1E103JE01J | 7 | 10n | Multilayer Ceramic Capacitors MLCC - SMD/SMT 0402, 0.01UF 25V C0G | MURATA 0402 | 10n
C45, C46, C58, C59, L8, L17, R32 | CRCW04020000Z0EDC | 7 | 0 Ohms | 0 Ohms jumper resistor 0402 | MURATA 0402, MURATA 0402, MURATA 0402, MURATA 0402, CoilCraft 0402, CoilCraft 0402, PANASONIC 0402 | 0 Ohms
C76, C88, C91, C94, C100, C101 | C0402C101J5GACTU | 6 | 100p | Multilayer Ceramic Capacitors MLCC - SMD/SMT 50V 100pF +/-0.05 | MURATA 0402 | 100p
C109, C110 | GRM1555C1H331JA01D | 2 | 330p | Multilayer Ceramic Capacitors MLCC - SMD/SMT 0402 330pF 50volts C0G 5% | MURATA 0402 | 330p
C113 | 0402N181F500CT | 1 | 180p | Multilayer Ceramic Capacitors MLCC - SMD/SMT 180pF 50V 1% 0402 NPO | MURATA 0402 | 180p
C114 | 04025A8R2BAT2A | 1 | 8.2p | Multilayer Ceramic Capacitors MLCC - SMD/SMT 50V 8.2pF C0G 0402 .1pF Tol | MURATA 0402 | 8.2p
D1, D2, D7, D8, D9, D10, D11, D12 | LTST-C190KRKT | 8 |  | Red 631nm LED Indication - Discrete 2V 0603 | LEDC1608X35N | LTST-C190KRKT
D3, D4 | 0402ESDB-MLP1 | 2 |  | ESD Suppressors / TVS Diodes ESD Protection Device, 0402, Bidirectional, 4V working, 15V breakdown, 0.05pF Cd | DIONC1105X44N | 0402ESDB-MLP1
J1 | M20-7832046, PPPC202LFBN-RC, 61304021821 | 1 |  | RPI 40-pin 2.54mm header, 2-rows, socket | rpi_zero | M20-7832046
J2, J3 | CON-SMA-EDGE-S | 2 |  | RF SMA Connectors / Coaxial Connectors SMA Female PCB Edge Mount | MOLEX_0732511150 | CON-SMA-EDGE-S
J6 | 10129383-912001ALF | 1 |  | Headers & Wire Housings ECONOSTIK HEADER DR VT SMT 2X6 | 10129383912001ALF | 10129383-912001ALF
J7 | CONUFL001-SMD-T | 1 |  | RF Connectors / Coaxial Connectors U.FL Straight Surface Mount Jack | LINX_CONUFL001-SMD-T | #NAME?
L1, L2, L4, L5, L13, L14, L15, L18, L20, L21 | BLM15HD182SN1D | 10 |  | Ferrite Beads 1800ohms GHz HiSpd | 0402 FERRITE BEAD | BLM15HD182SN1D
L3 | 0402CS-5N6XGLW | 1 | 5.6n | Fixed Inductors 1005 5.6nH Unshld 2% 760mA 83mOhms | CoilCraft 0402 | 5.6n
R1, R6, R7, R33, R34, R47, R48, R49, R50, R51, R52 | CRCW0402470RFKED | 11 | 470 | Thick Film Resistors - SMD 1/16watt 470ohms 1% | PANASONIC 0402 | 470
R2, R8, R9, R11, R16, R30 | RC0402FR-07102KL | 6 | 102k | Thick Film Resistors - SMD 102 kOhms 62.5mW 0402 1% | PANASONIC 0402 | 102k
R3, R5, R14, R15, R27, R28, R35, R43, R44 | CRCW040210K0FKEDC | 9 | 10k | Thick Film Resistors - SMD 0402 1/16watt 10Kohms 1% | PANASONIC 0402 | 10k
R13, R17, R18, R19, R20, R22, R24 | CRCW0402100RFKEDC | 7 | 100 | Thick Film Resistors - SMD 1/16watt 100ohms 1% | PANASONIC 0402 | 100
R21, R23 | CRCW0402162RFKED | 2 | 162 | Thick Film Resistors - SMD 1/16watt 162ohms 1% | PANASONIC 0402 | 162
R36 | CRCW040222K0FKEDC | 1 | 22k | Thick Film Resistors - SMD 1/16watt 22kohms 1% | PANASONIC 0402 | 22k
R42, R45, R46 | CRCW04021K00FKEDC | 3 | 1k | Thick Film Resistors - SMD 0402 1/16watt 1Kohms 1% | PANASONIC 0402 | 1k
S1 | EVQ9P701P | 1 |  | Tactile Switches SMD 3.5X2.9MM SID-OP L SHAPED TERM 1.6N | EVQ9P701P | EVQ9P701P
U1 | AT86RF215-ZU | 1 |  | RF Transceiver Dual Band IEEE 802.15.4 TRX, 48QFN | QFN50P700X700X90-49N-D | AT86RF215-ZU
U2 | 2450FB15A050E | 1 |  | 2.45 GHz EIA 0805 Balun / Filter Combination 50 / 50Ohm 0805 (2012 Metric) | FIL_0896BM15E0025E | 2450FB15A050E
U3 | ATX-12-F-26.000MHz-F05-T | 1 | 26 MHz | TCXO Oscillators XTAL OSC TCXO 26 MHz Clipped Sinewave 0.5ppm -40C +85C 2.5x2mm, 1.6-3.6V | TCXO_4_25x20 | ATX-12-F-26.000MHz-F05-T
U4 | 0896BM15E0025E | 1 |  | RF Balun 863MHz ~ 928MHz 50 / 50Ohm 0805 (2012 Metric) | FIL_0896BM15E0025E | 0896BM15E0025E
U5 | NCV8187AMT330TAG | 1 |  | LDO Voltage Regulators 1.2A 3.3V Active discharge | SON65P200X200X80-7N | NCV8187AMT330TAG
U6 | TLV7111225DSER | 1 |  | LDO Voltage Regulators Dual 200mA Output Lo Noise Hi PSRR LDO Rg | SON50P150X150X80-6N | TLV7111225DSER
U9, U15 | MAAM-011229 | 2 |  | RF Amplifier .05-4GHz NF 2.2dBmax -40C +85C | PDFN_2MM_8LEAD | MAAM-011229
U10 | LFCN-2250+ | 1 |  | LTCC Low Pass Filter, DC - 2200 MHz, 50O | FV1206 | LFCN-2250+
U11, U18 | SKY13373-460LF | 2 |  | RF Switch ICs .1-6.0GHz SP3T IL .45dB @ 2.5GHz | QFN50P200X200X60-13N-D | SKY13373-460LF
U12 | HFCN-2275+ | 1 |  | Signal Conditioning HI PASS FLTR / SURF MT / RoHS | FV1206 | HFCN-2275+
U13, U14 | CG2164X3-C2 | 2 |  | RF Switch ICs 2.5 and 6GHz DPDT 802.11a/b/g/n/ac | SON50P150X150X40-7N | CG2164X3-C2
U16 | ICE40LP1K-QN84 | 1 |  | FPGA - Field Programmable Gate Array iCE40LP 1280 LUTs 1.2V Ultra Low-Power | LATTICE_ICE40LP1K-QN84 | ICE40LP1K-QN84
U19, U20 | CG2409X3-C2 | 2 |  | RF Switch ICs 50-6000MHz SPDT 802.11a/b/g/n/ac | SON50P150X150X40-7N | CG2409X3-C2
U21 | TC4-19G2+ | 1 |  | Audio Transformers / Signal Transformers TC XFMR / SURF MOUNT / RoHS, Alternatives - TC4-19+ | TC4-19 | TC4-19G2+
U22 | RFFC5072TR13 | 1 |  | RF Mixer LO Freq. 85-4200MHz WB Synthesizer/VCO | QFN50P500X500X85_HS-33N | RFFC5072TR13
U23 | TC1-1-13M+ | 1 |  | Transformers / Signal Transformers TC XFMR / SURF MOUNT | TC1-1-13M | TC1-1-13M+
U25 | SG-8018CG 125.0000M-TJHSA3 | 1 |  | Standard Clock Oscillators SG-8018CG 125.0000M-TJHPA3: MHZ OSC 1.8V 3.3V +/-50PPM -40 105C O/E 250TR | SG-8018CG | SG-8018CG 125.0000M-TJHPA3
U26 | CAT24C32HU4I-GT3 | 1 |  | EEPROM Serial-I2C 32K 4Kx8 1.8V/5V UDFN8 CAT24C32HU4I-GT3 | SON50P300X200X55-9N | CAT24C32HU4I-GT3
U27, U28 | MMBT3904,215 | 2 |  | Bipolar Transistors - BJT TRANS BIPOLAR | SOT95P240X111-3N | MMBT3904,215

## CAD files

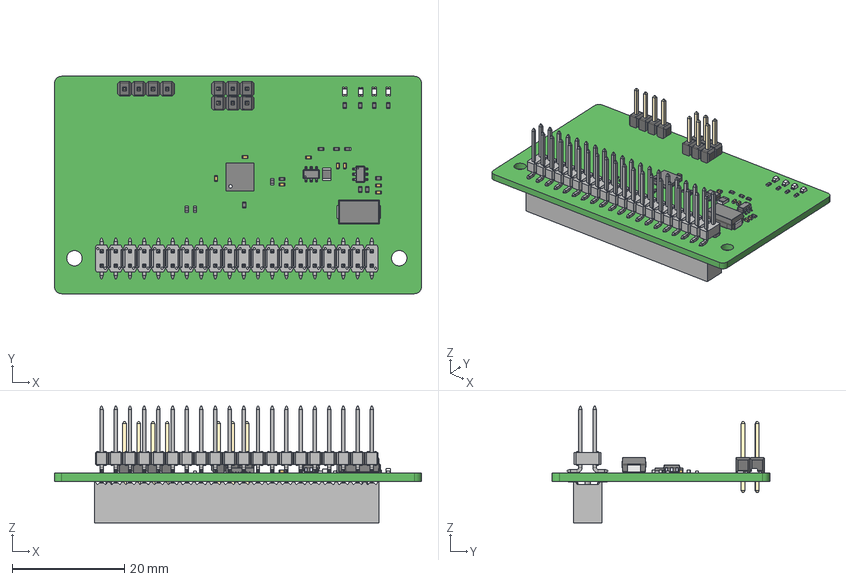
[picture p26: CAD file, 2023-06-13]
hardware/hat_power_monitor_r1.0/ExportSTEP/pcb.step
65.5 x 38.9 x 20.9 mm
Mid_Body x 16
Open_CASCADE_STEP_translator_6.8_26.2.1 x 30
Mark x 16
Open_CASCADE_STEP_translator_6.8_35.1.1 x 8
Open_CASCADE_STEP_translator_6.8_35.1.2 x 8
Open_CASCADE_STEP_translator_6.8_35.2.1 x 8
Open_CASCADE_STEP_translator_6.8_15.1.1
Lead x 2
holder x 3
pin x 10
Open_CASCADE_STEP_translator_6.8_9.2.1 x 2
LTST-C190KRKT--3DModel-STEP-56544 x 4
Open_CASCADE_STEP_translator_6.8_19.1
Open_CASCADE_STEP_translator_6.8_19.2.1
Thermal_Shape
Open_CASCADE_STEP_translator_6.8_19.4.1 x 32
77310_Y08SMT x 40
C-137-0120
SSM-120-L-DV-A_body

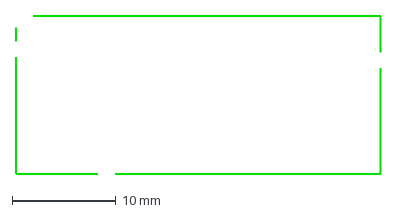
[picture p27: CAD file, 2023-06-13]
hardware/rev2/assembly/dxf/top_emi_drawing.dxf
35.2 x 15.2 mm

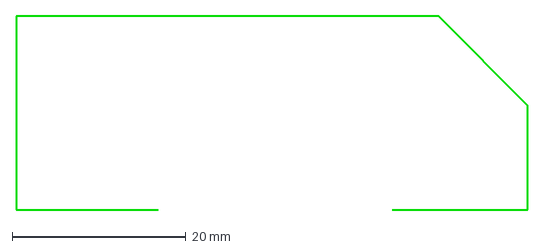
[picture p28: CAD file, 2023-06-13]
hardware/rev2/assembly/dxf/bottom_emi_drawing.dxf
59.0 x 22.2 mm

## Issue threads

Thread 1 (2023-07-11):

Question identify the antenna on the picture

Amefaux, 2023-07-11:
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

Anyone know the antenna from the picture?
It looks like DVB T2 dual antenna but for stand and it seems have sma connector.

great9, 2024-09-03:
This is the telescopic antenna that comes in the RTL-SDR kit.

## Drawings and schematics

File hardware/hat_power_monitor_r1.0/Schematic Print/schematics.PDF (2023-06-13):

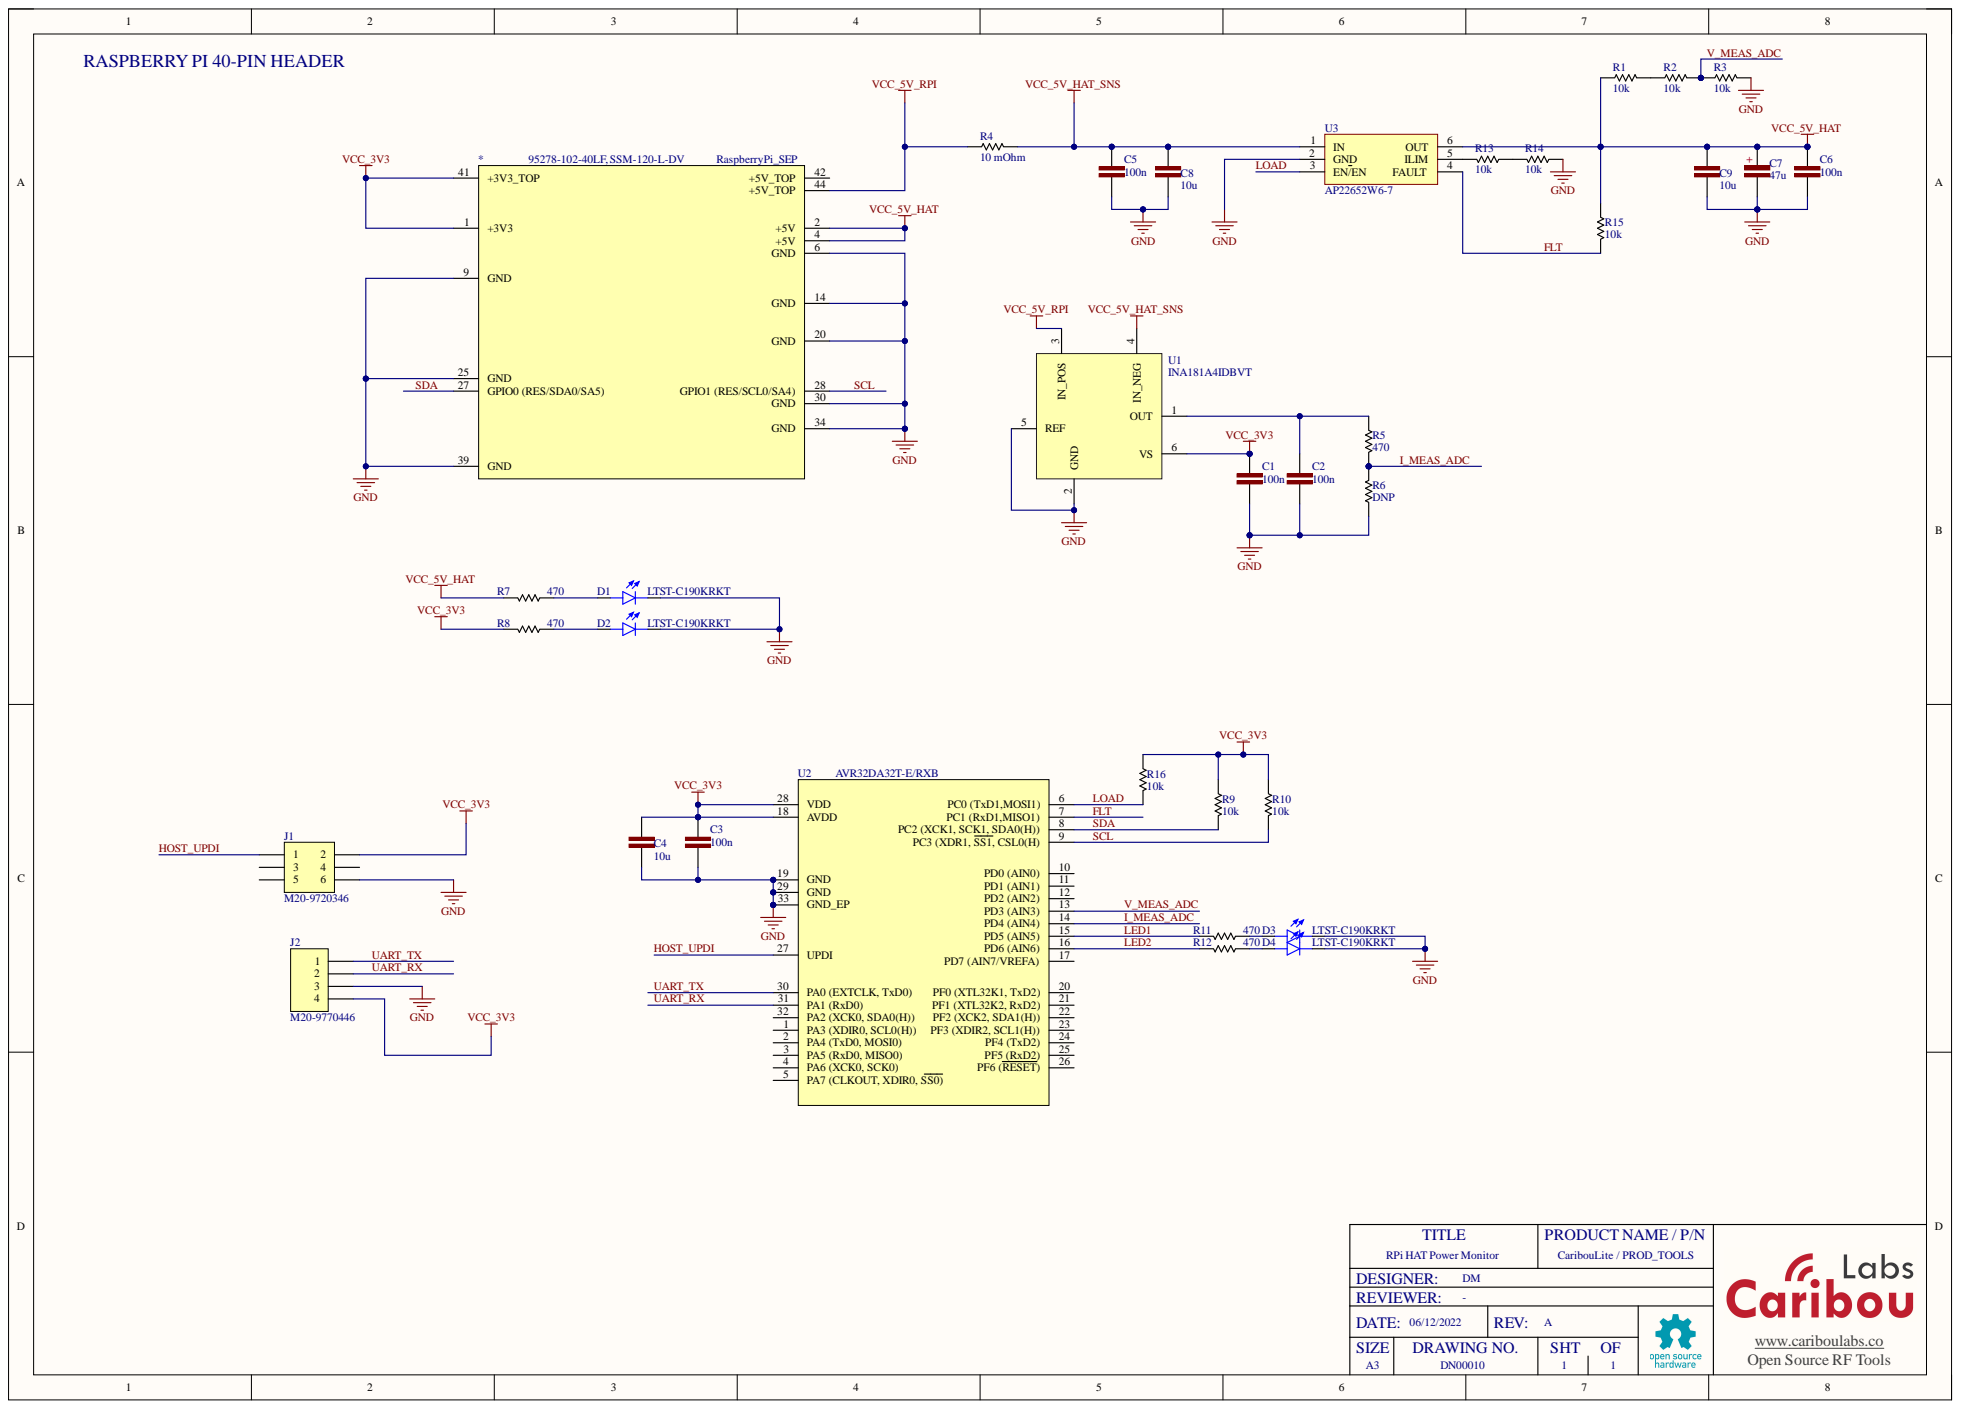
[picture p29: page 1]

RASPBERRY PI 40-PIN HEADER

LOAD | EN/EN 3

AVDD 18
GND 19 | SDA

SCL

www.cariboulabs.co
Open Source RF Tools

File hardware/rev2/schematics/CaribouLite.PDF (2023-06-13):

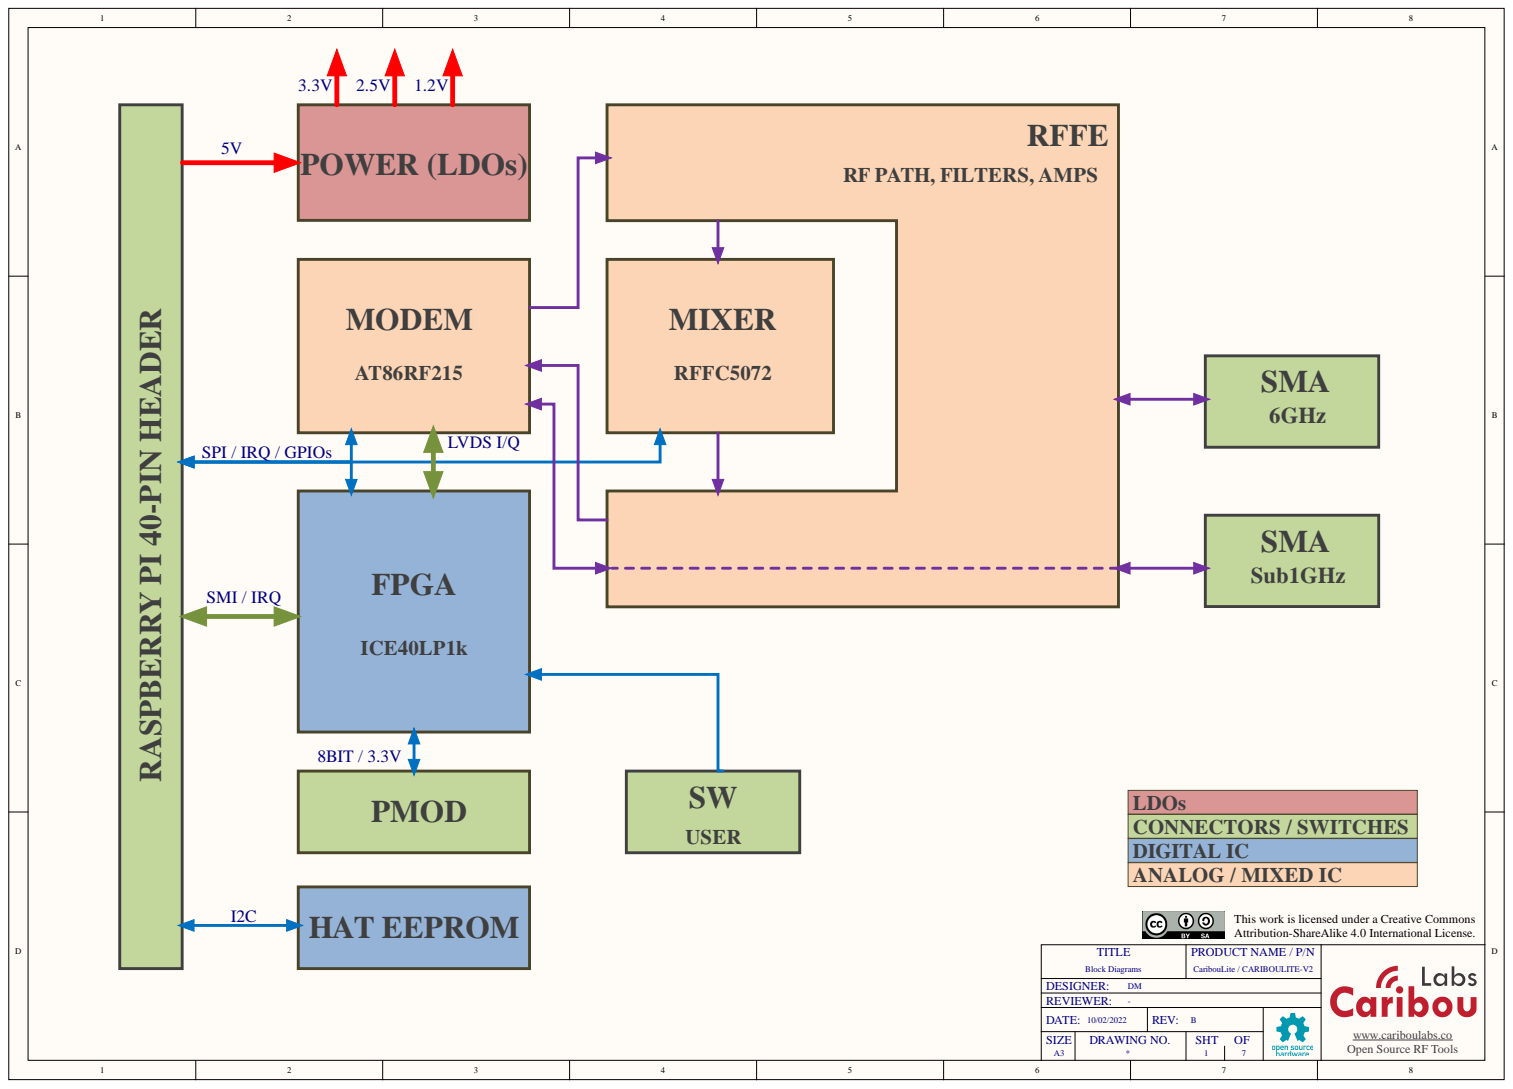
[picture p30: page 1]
SIZE; DRAWING NO.; CaribouLite / CARIBOULITE-V2; TITLE; PRODUCT NAME / P/N; Block Diagrams; POWER (LDOs); HAT EEPROM; 8BIT / 3.3V; LVDS I/Q; SMI / IRQ

RF PATH, FILTERS, AMPS

SPI / IRQ / GPIOs

LDOs
CONNECTORS / SWITCHES
DIGITAL IC
ANALOG / MIXED IC

This work is licensed under a Creative Commons
Attribution-ShareAlike 4.0 International License.

www.cariboulabs.co
Open Source RF Tools

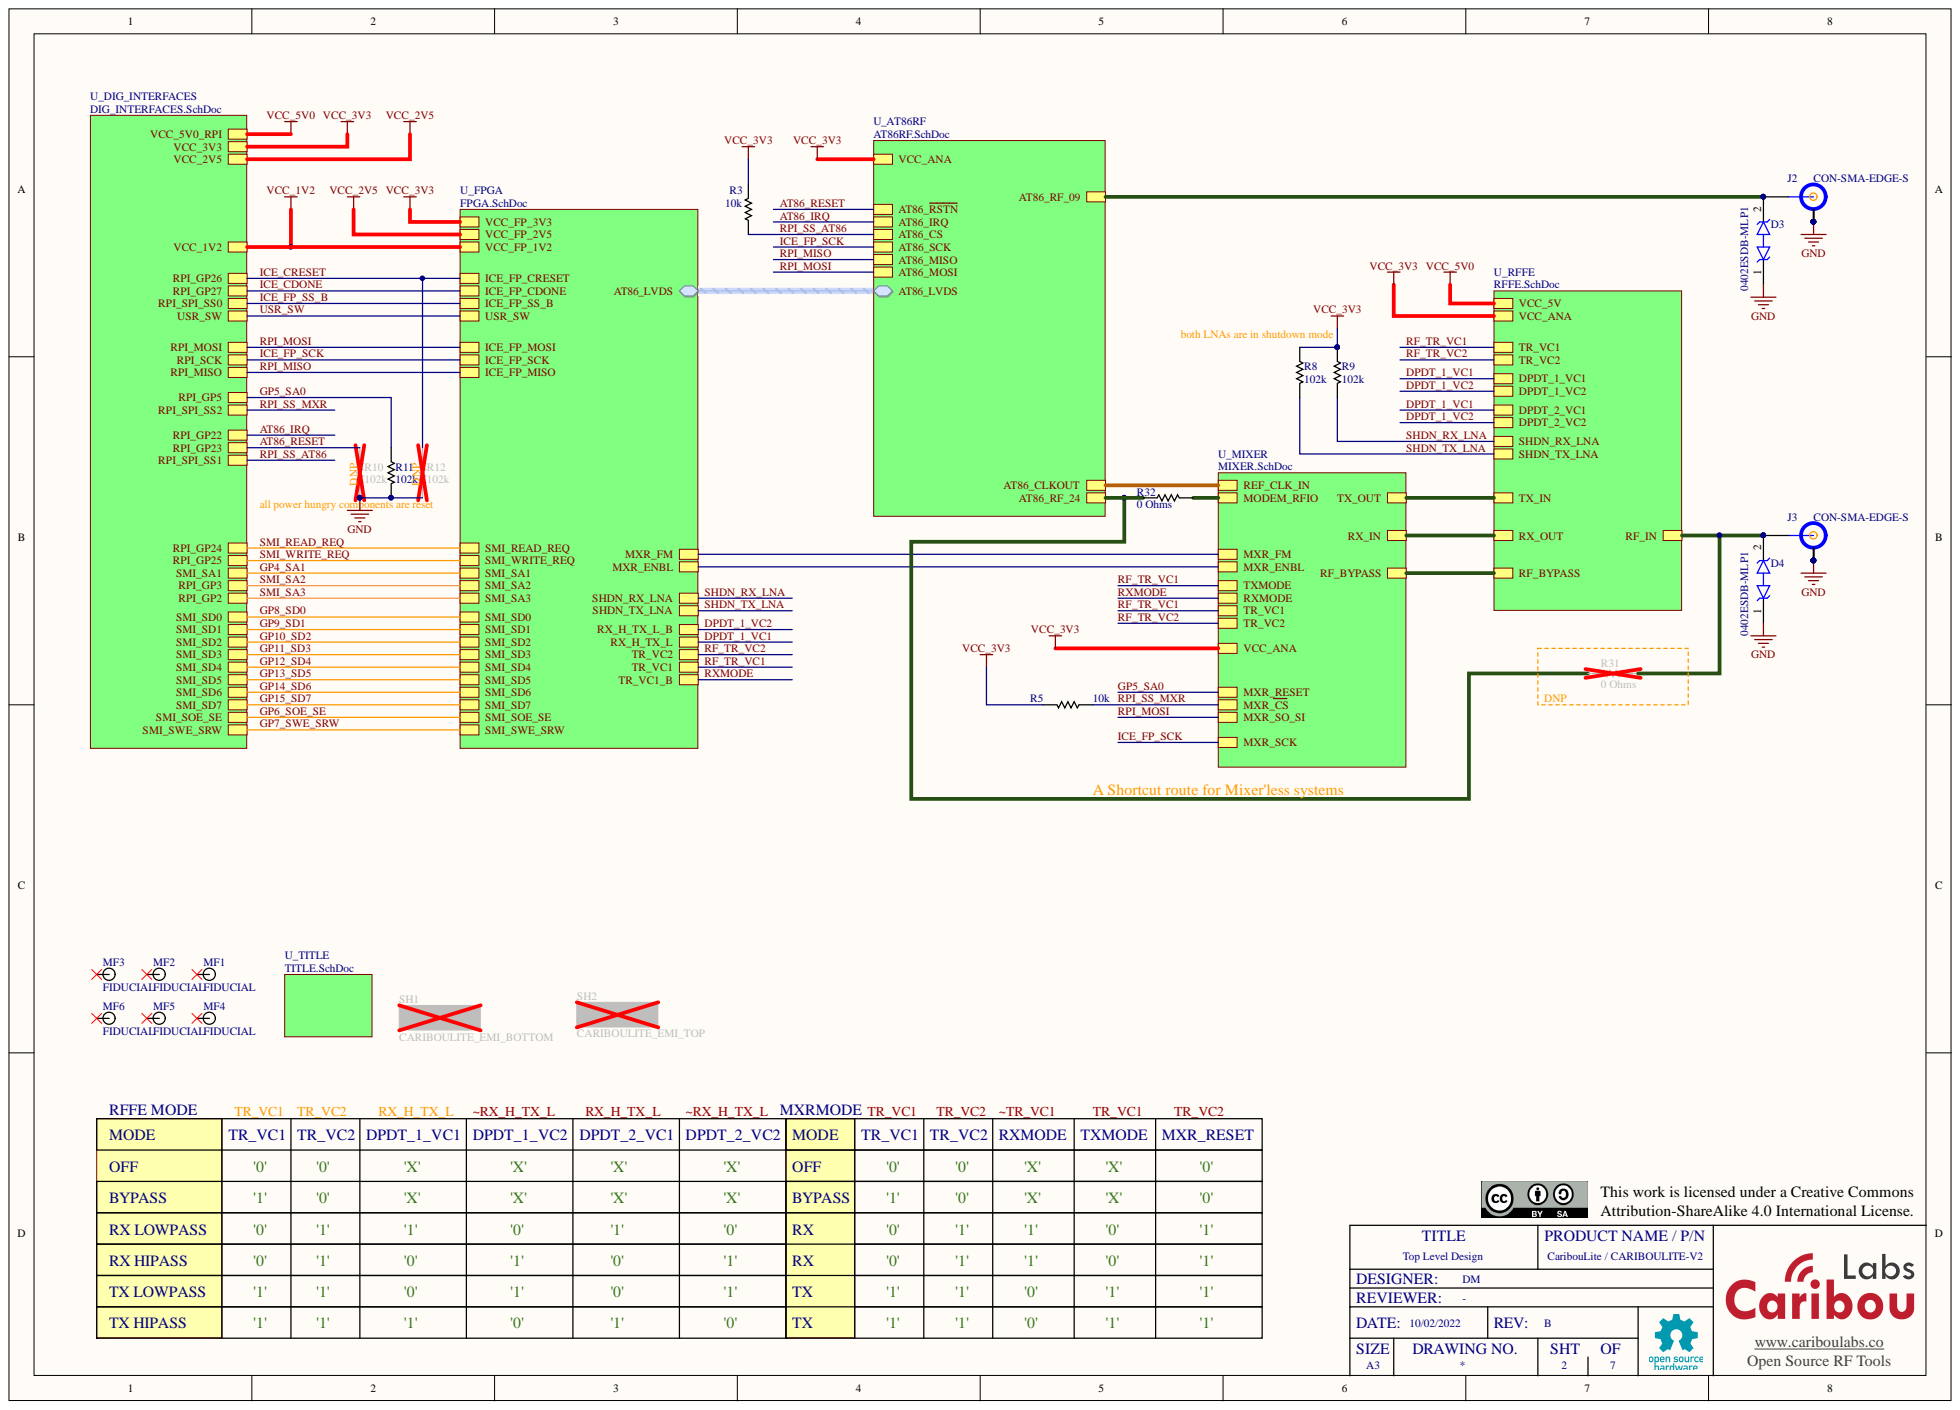
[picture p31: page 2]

ICE_CDONE
ICE_FP_SS_B
USR_SW

both LNAs are in shutdown mode

RPI_MISO

all power hungry components are reset

A Shortcut route for Mixer'less systems

MODE | TR_VC1 | TR_VC2 | DPDT_1_VC1 | DPDT_1_VC2 | DPDT_2_VC1 | DPDT_2_VC2 | MODE | TR_VC1 | TR_VC2 | RXMODE | TXMODE | MXR_RESET

OFF | '0' | '0' | 'X' | 'X' | 'X' | 'X' | OFF | '0' | '0' | 'X' | 'X' | '0'

This work is licensed under a Creative Commons
Attribution-ShareAlike 4.0 International License.

BYPASS | '1' | '0' | 'X' | 'X' | 'X' | 'X' | BYPASS | '1' | '0' | 'X' | 'X' | '0'

RX LOWPASS | '0' | '1' | '1' | '0' | '1' | '0' | RX | '0' | '1' | '1' | '0' | '1'

RX HIPASS | '0' | '1' | '0' | '1' | '0' | '1' | RX | '0' | '1' | '1' | '0' | '1'

TX LOWPASS | '1' | '1' | '0' | '1' | '0' | '1' | TX | '1' | '1' | '0' | '1' | '1'

TX HIPASS | '1' | '1' | '1' | '0' | '1' | '0' | TX | '1' | '1' | '0' | '1' | '1'

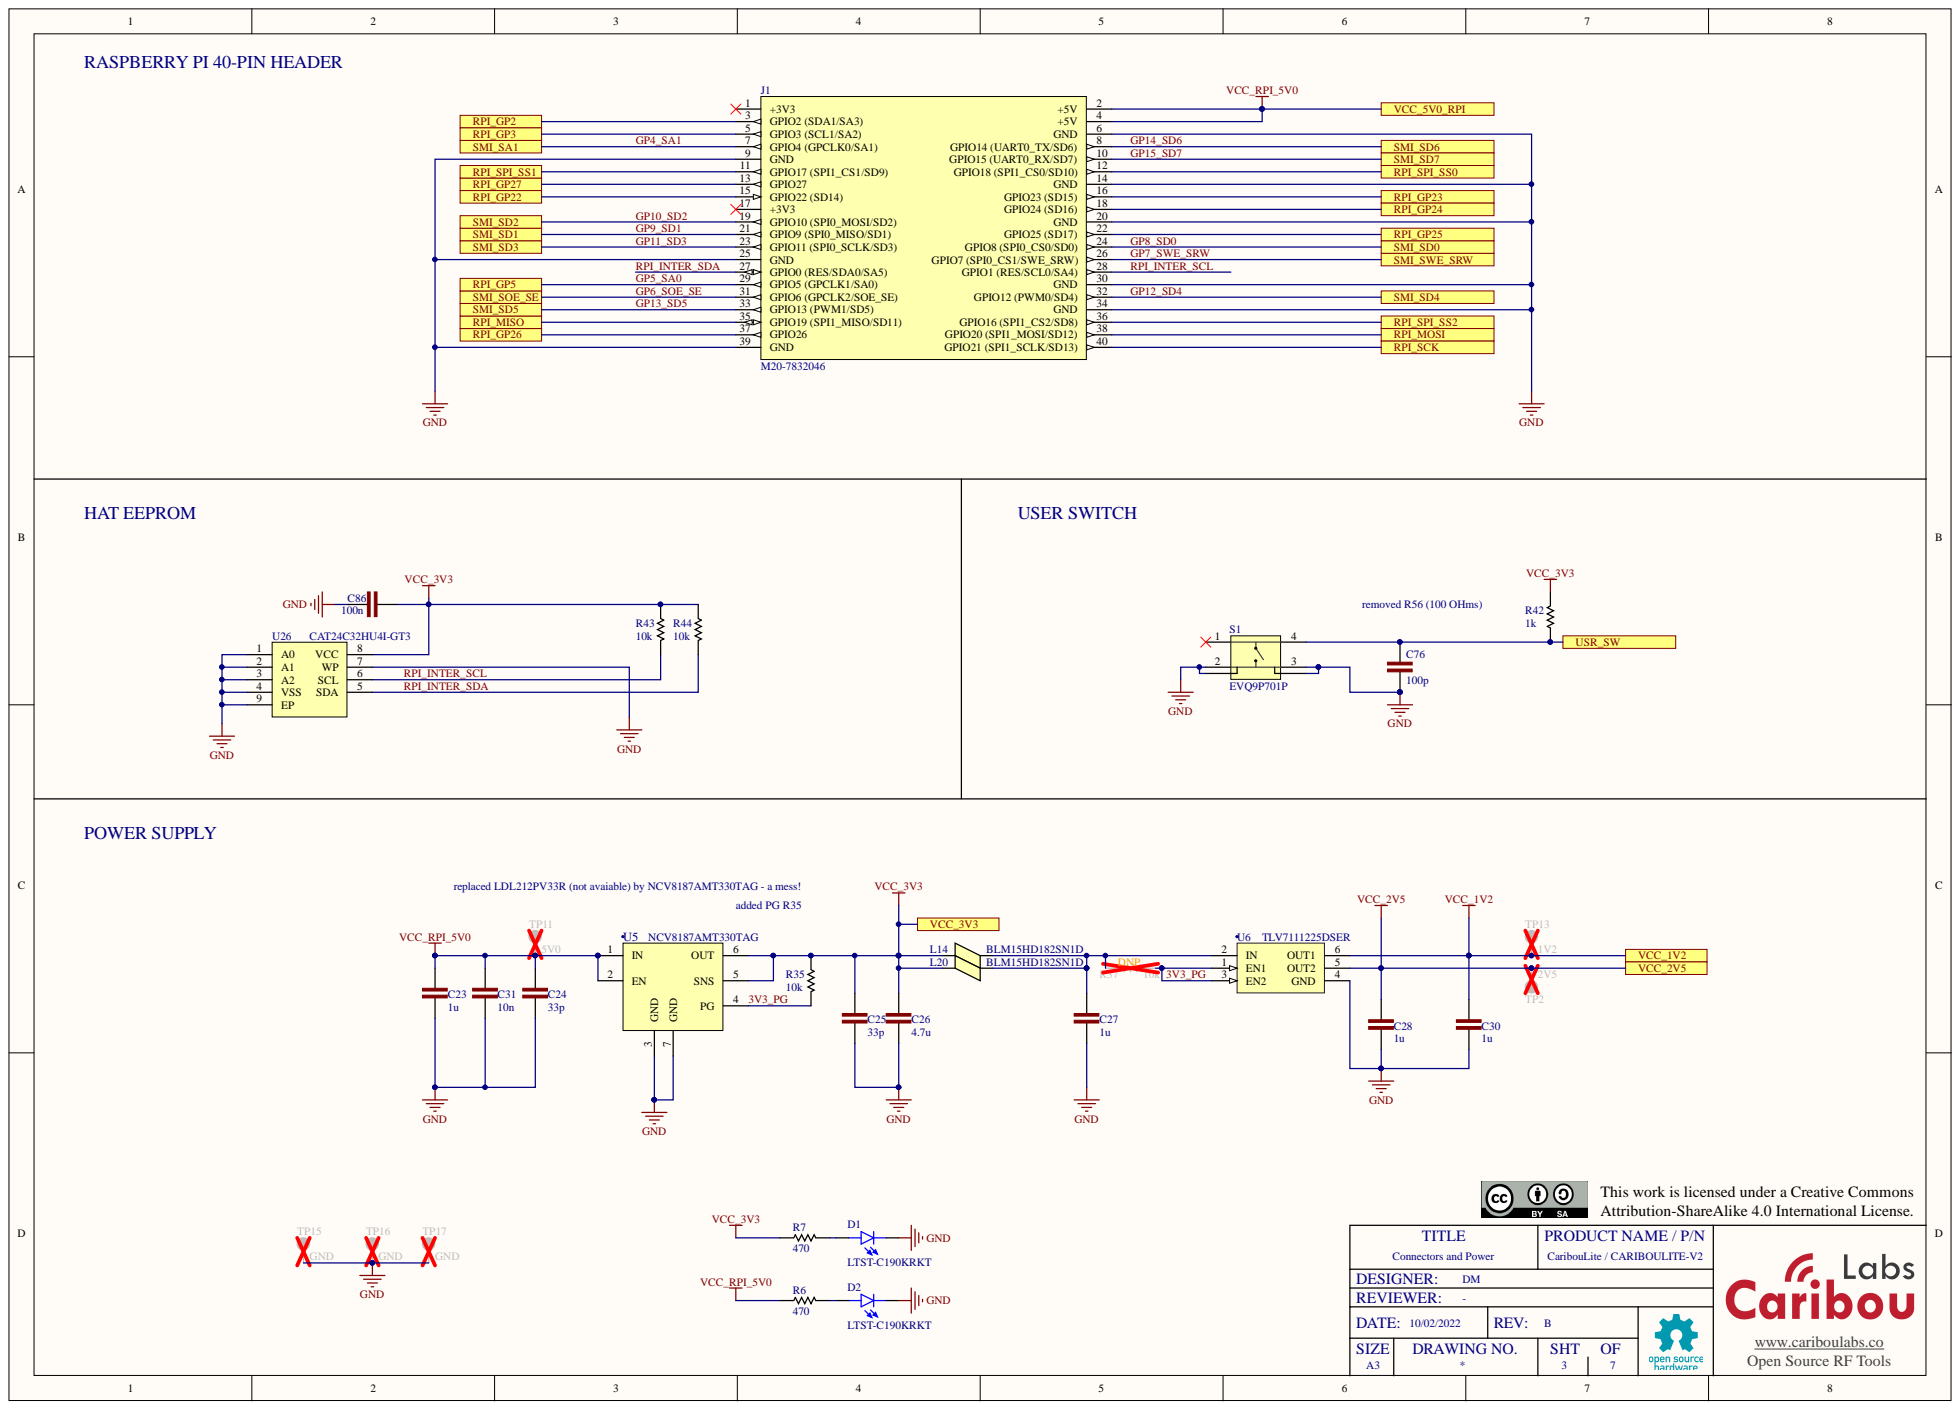
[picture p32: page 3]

RASPBERRY PI 40-PIN HEADER

VSS 4 | RPI_INTER_SDA
EP 9

replaced LDL212PV33R (not avaiable) by NCV8187AMT330TAG - a mess!

This work is licensed under a Creative Commons
Attribution-ShareAlike 4.0 International License.

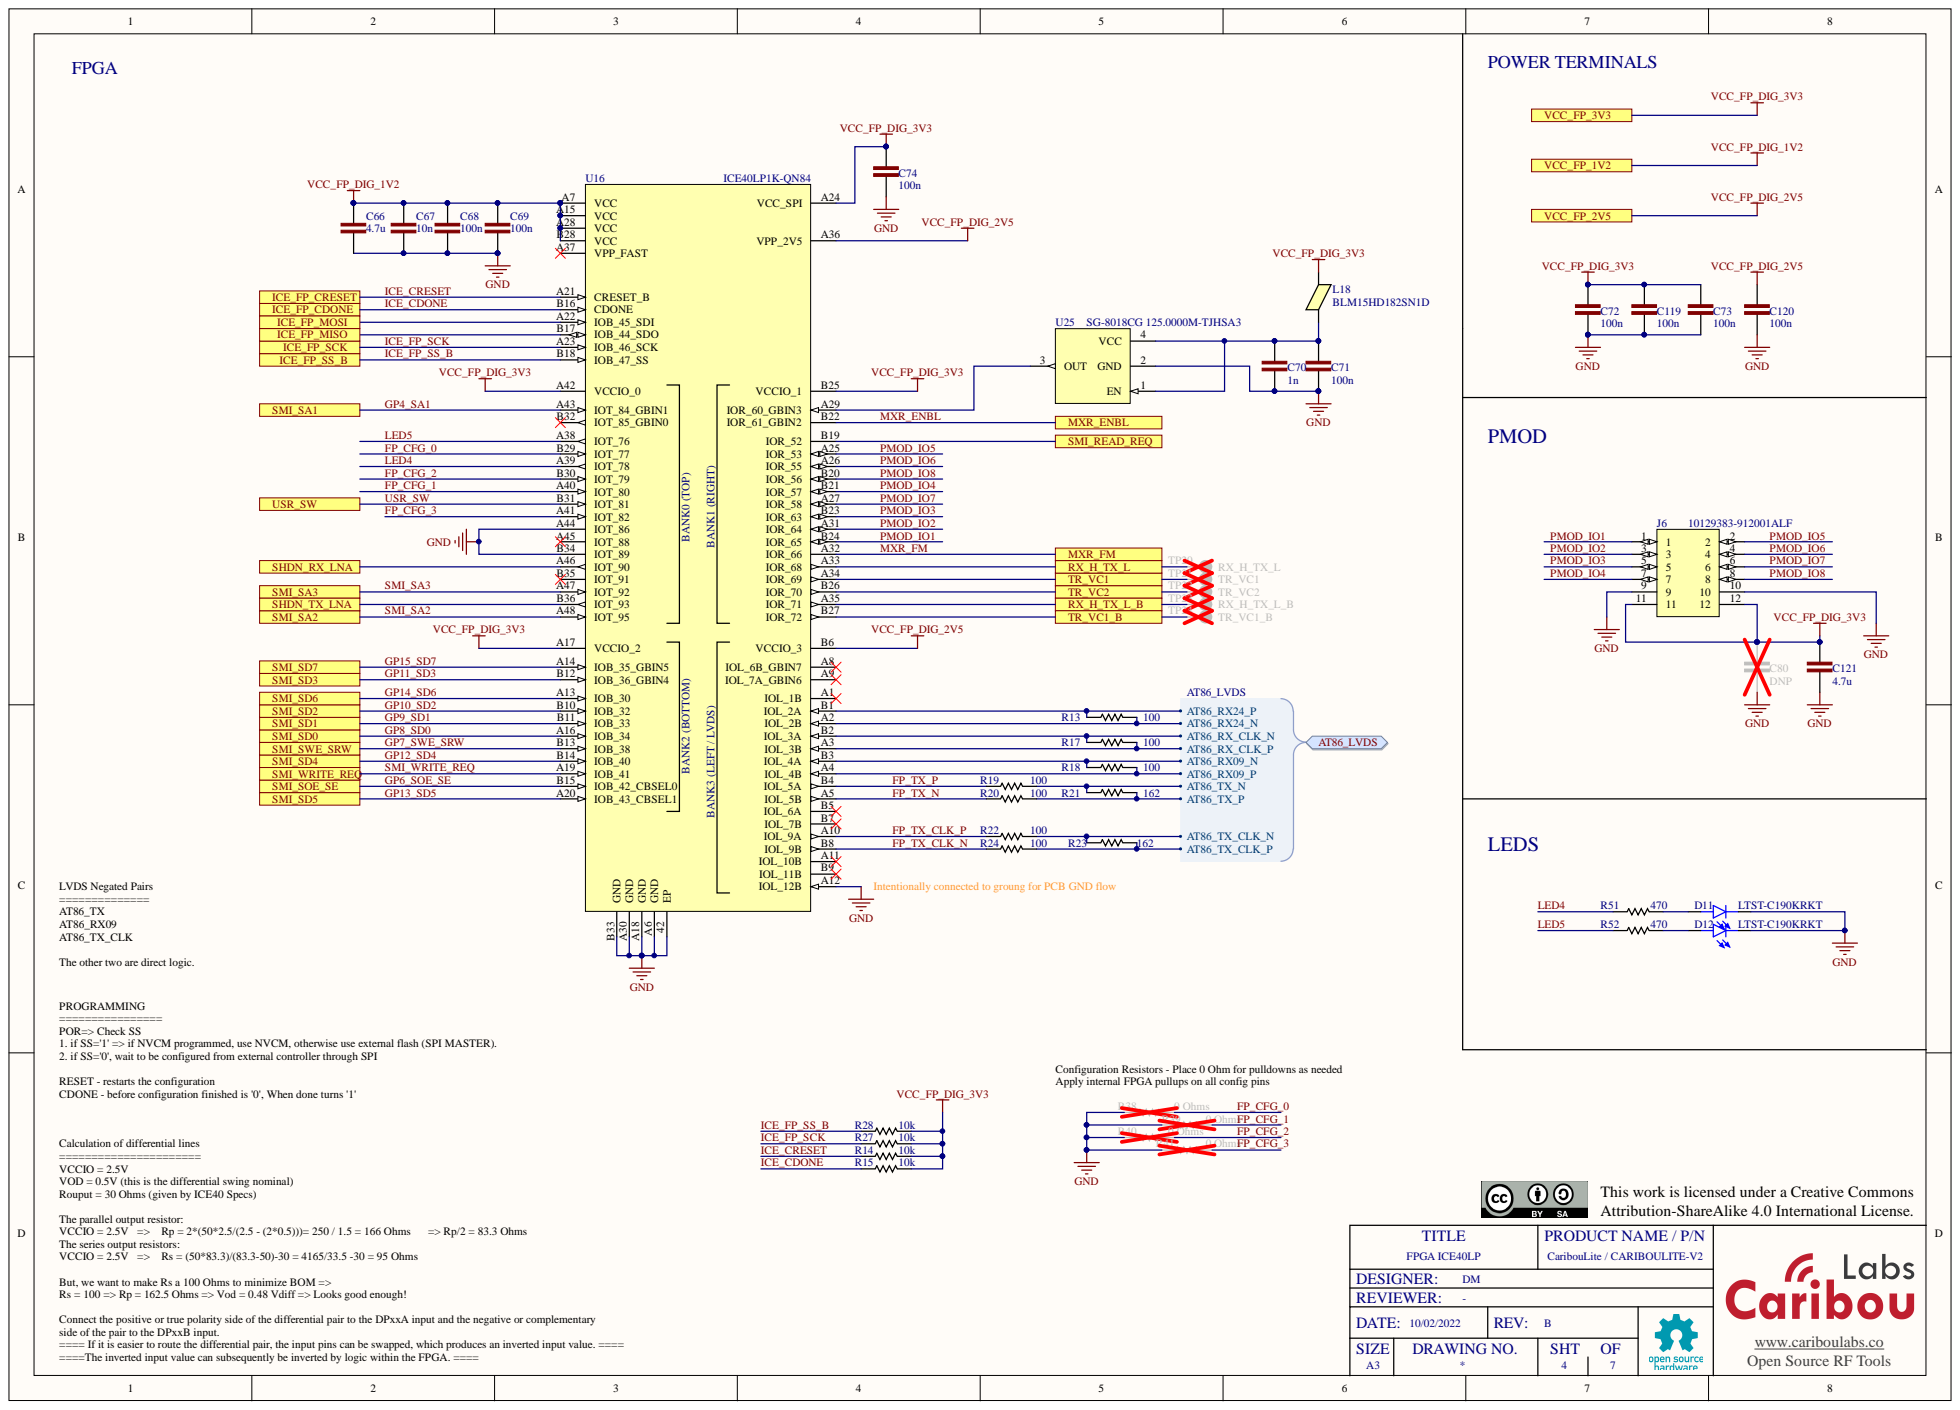
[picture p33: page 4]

Intentionally connected to groung for PCB GND flow

The other two are direct logic.

PROGRAMMING
POR=> Check SS
1. if SS='1' => if NVCM programmed, use NVCM, otherwise use external flash (SPI MASTER).
2. if SS='0', wait to be configured from external controller through SPI

Configuration Resistors - Place 0 Ohm for pulldowns as needed
Apply internal FPGA pullups on all config pins

RESET - restarts the configuration
CDONE - before configuration finished is '0', When done turns '1'

Calculation of differential lines
VCCIO = 2.5V
VOD = 0.5V (this is the differential swing nominal)
Rouput = 30 Ohms (given by ICE40 Specs)

This work is licensed under a Creative Commons
Attribution-ShareAlike 4.0 International License.

The parallel output resistor:
The series output resistors:
VCCIO = 2.5V => Rs = (50*83.3)/(83.3-50)-30 = 4165/33.5 -30 = 95 Ohms

But, we want to make Rs a 100 Ohms to minimize BOM =>
Rs = 100 => Rp = 162.5 Ohms => Vod = 0.48 Vdiff => Looks good enough!

Connect the positive or true polarity side of the differential pair to the DPxxA input and the negative or complementary
side of the pair to the DPxxB input.
==== If it is easier to route the differential pair, the input pins can be swapped, which produces an inverted input value. ====
====The inverted input value can subsequently be inverted by logic within the FPGA. ====

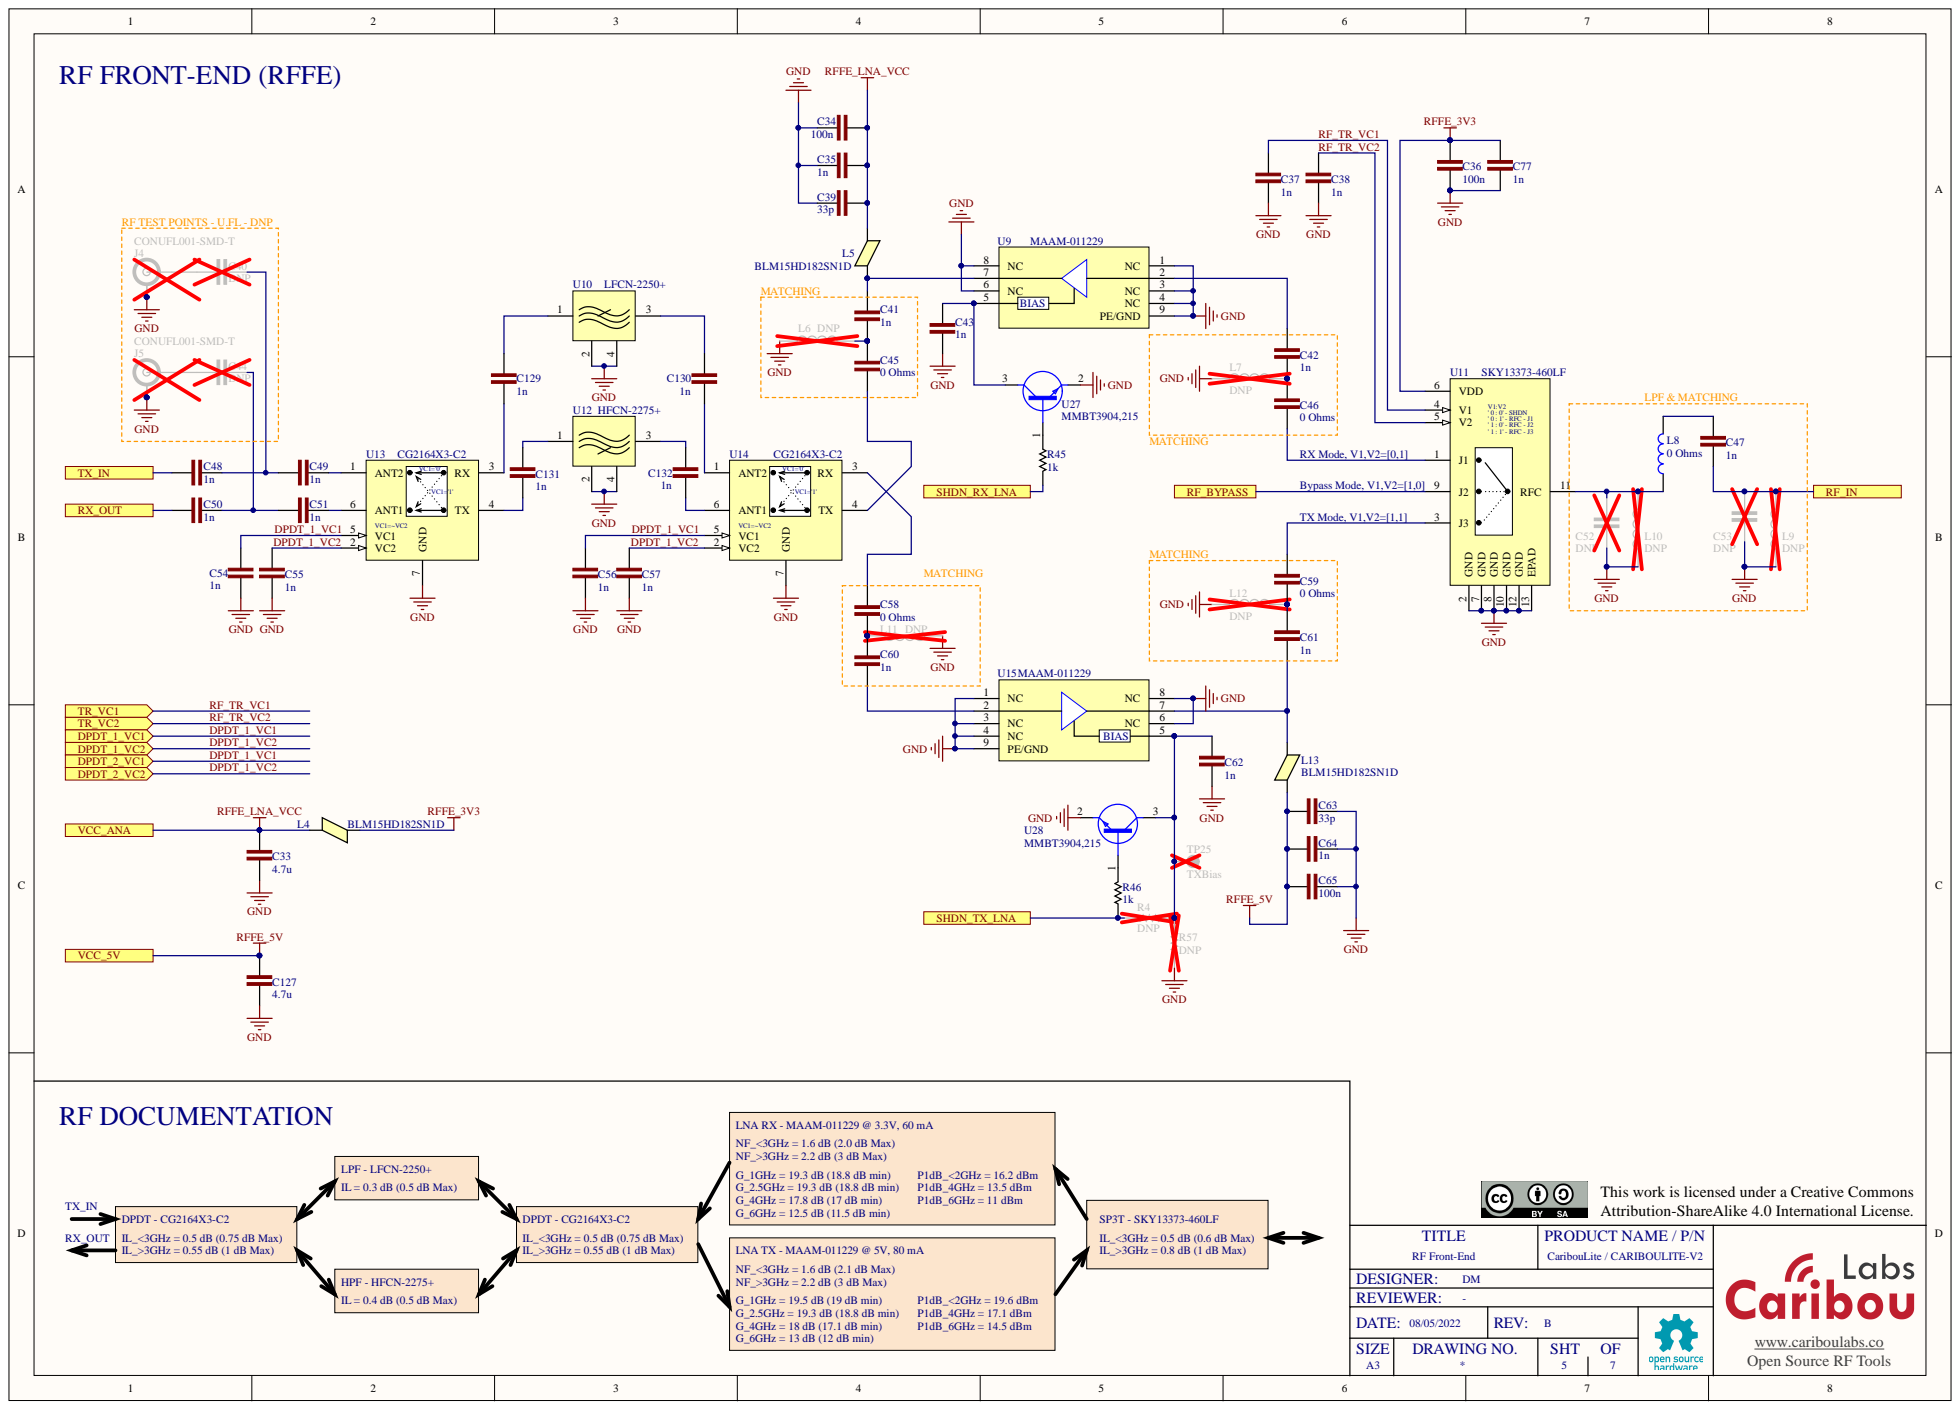
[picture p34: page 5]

RF FRONT-END (RFFE)

RF TEST POINTS - U.FL - DNP
CONUFL001-SMD-T

NC 3

LNA RX - MAAM-011229 @ 3.3V, 60 mA
NF_<3GHz = 1.6 dB (2.0 dB Max)
NF_>3GHz = 2.2 dB (3 dB Max)
G_1GHz = 19.3 dB (18.8 dB min)
G_2.5GHz = 19.3 dB (18.8 dB min)
G_4GHz = 17.8 dB (17 dB min)
G_6GHz = 12.5 dB (11.5 dB min)

LPF - LFCN-2250+
IL = 0.3 dB (0.5 dB Max)

This work is licensed under a Creative Commons
Attribution-ShareAlike 4.0 International License.

LNA TX - MAAM-011229 @ 5V, 80 mA
NF_<3GHz = 1.6 dB (2.1 dB Max)
G_1GHz = 19.5 dB (19 dB min)
G_4GHz = 18 dB (17.1 dB min)
G_6GHz = 13 dB (12 dB min)

HPF - HFCN-2275+
IL = 0.4 dB (0.5 dB Max)

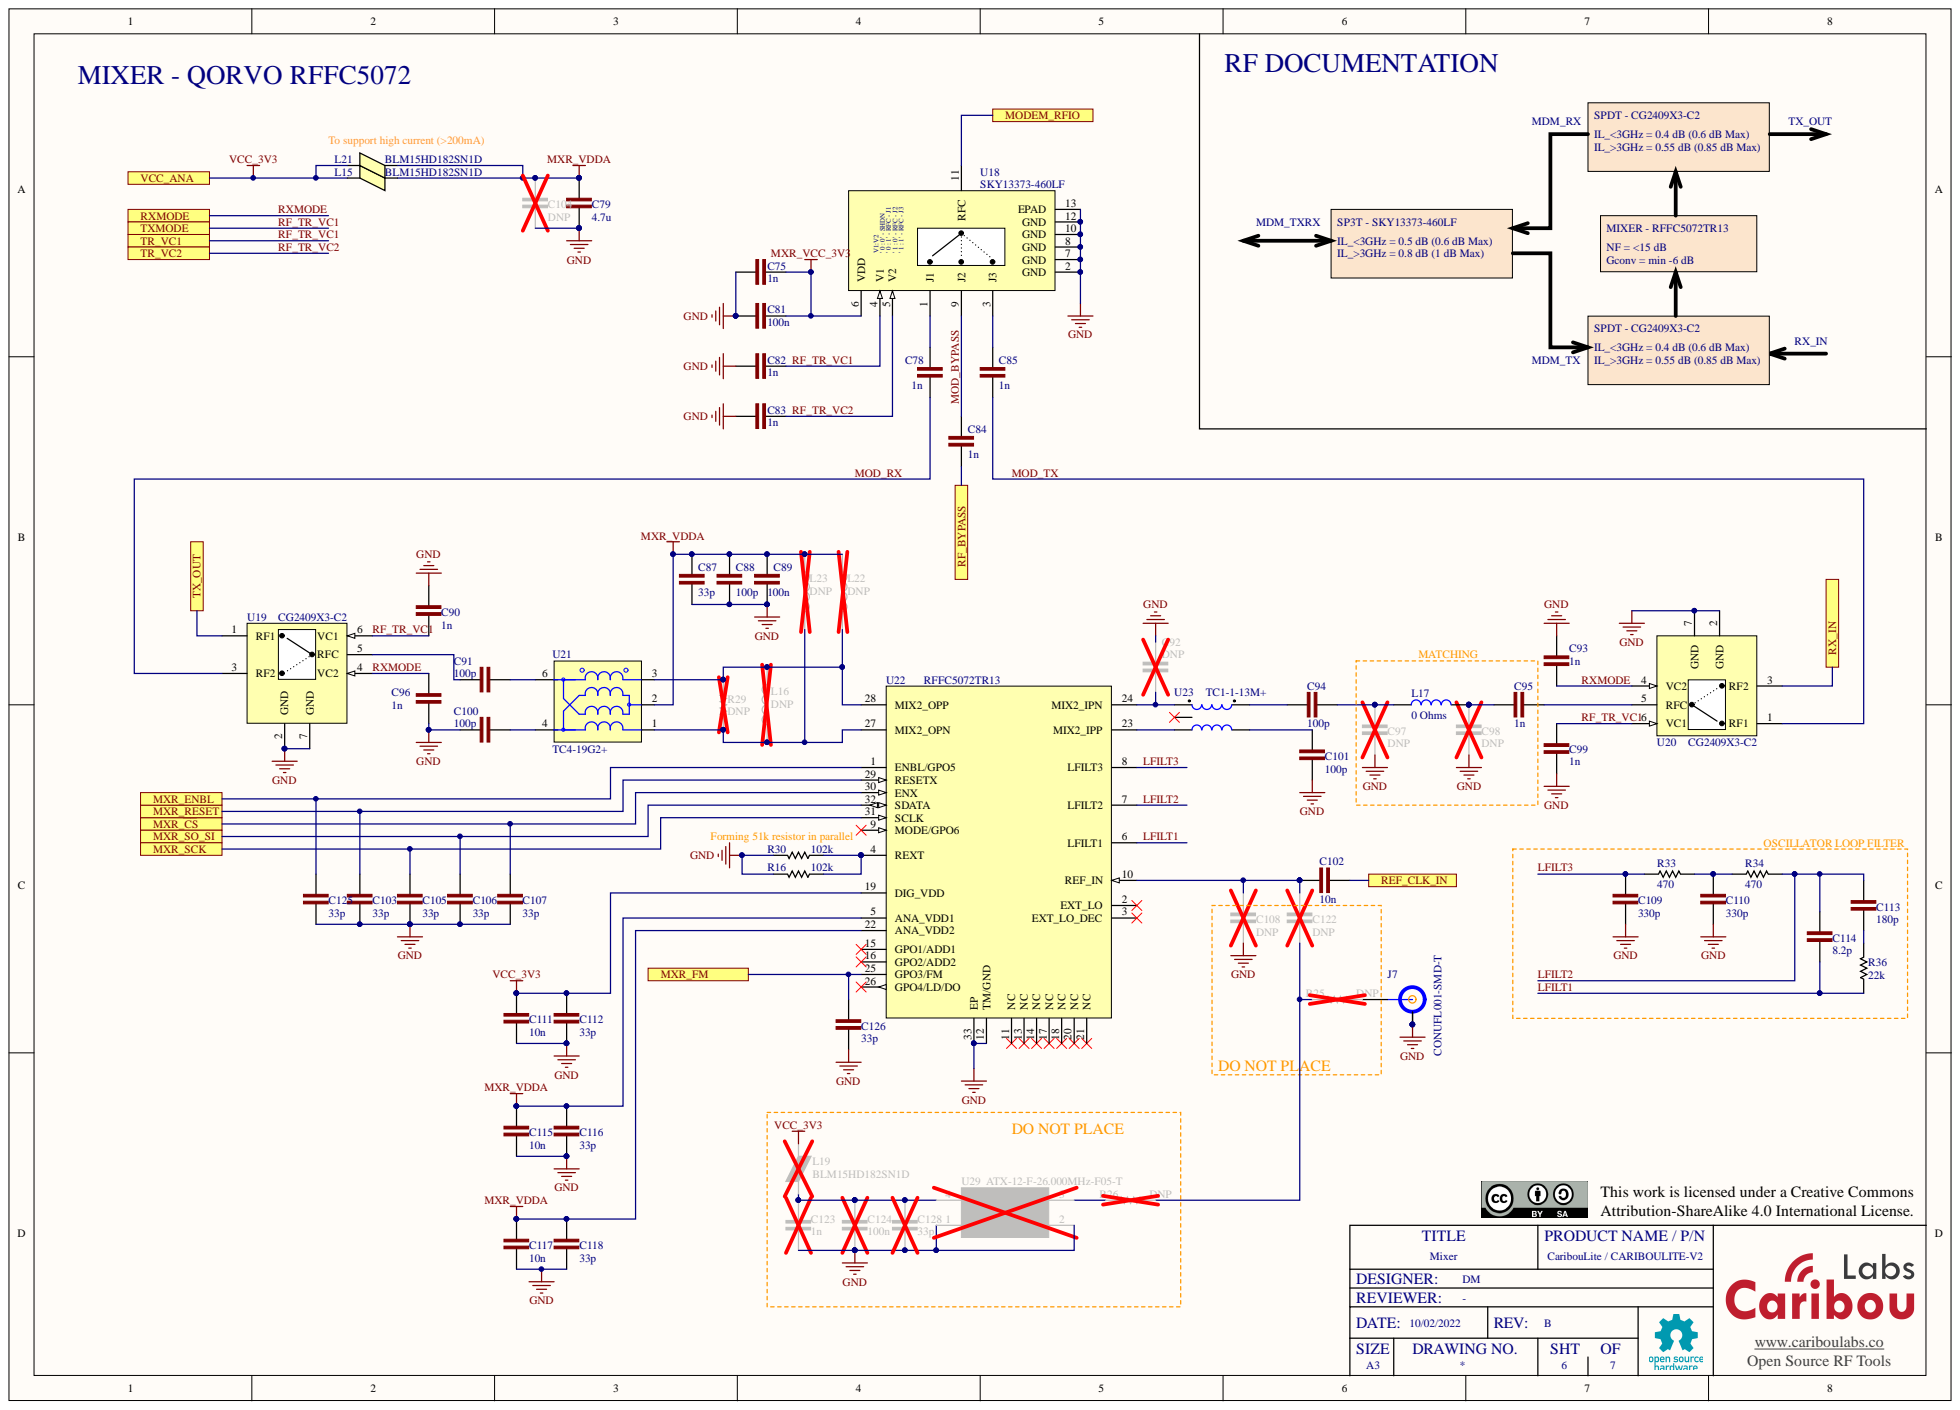
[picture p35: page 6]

RF DOCUMENTATION MIXER - QORVO RFFC5072

To support high current (>200mA)

RXMODE

GND | RESETX 29

ENX 30

MXR_ENBL | | SCLK 31 SDATA 32
MXR_RESET
MXR_CS | | | MODE/GPO6 9
MXR_SO_SI | | | | REXT 4

Forming 51k resistor in parallel

C107 33p | ANA_VDD1 5

ANA_VDD2 22

This work is licensed under a Creative Commons
Attribution-ShareAlike 4.0 International License.

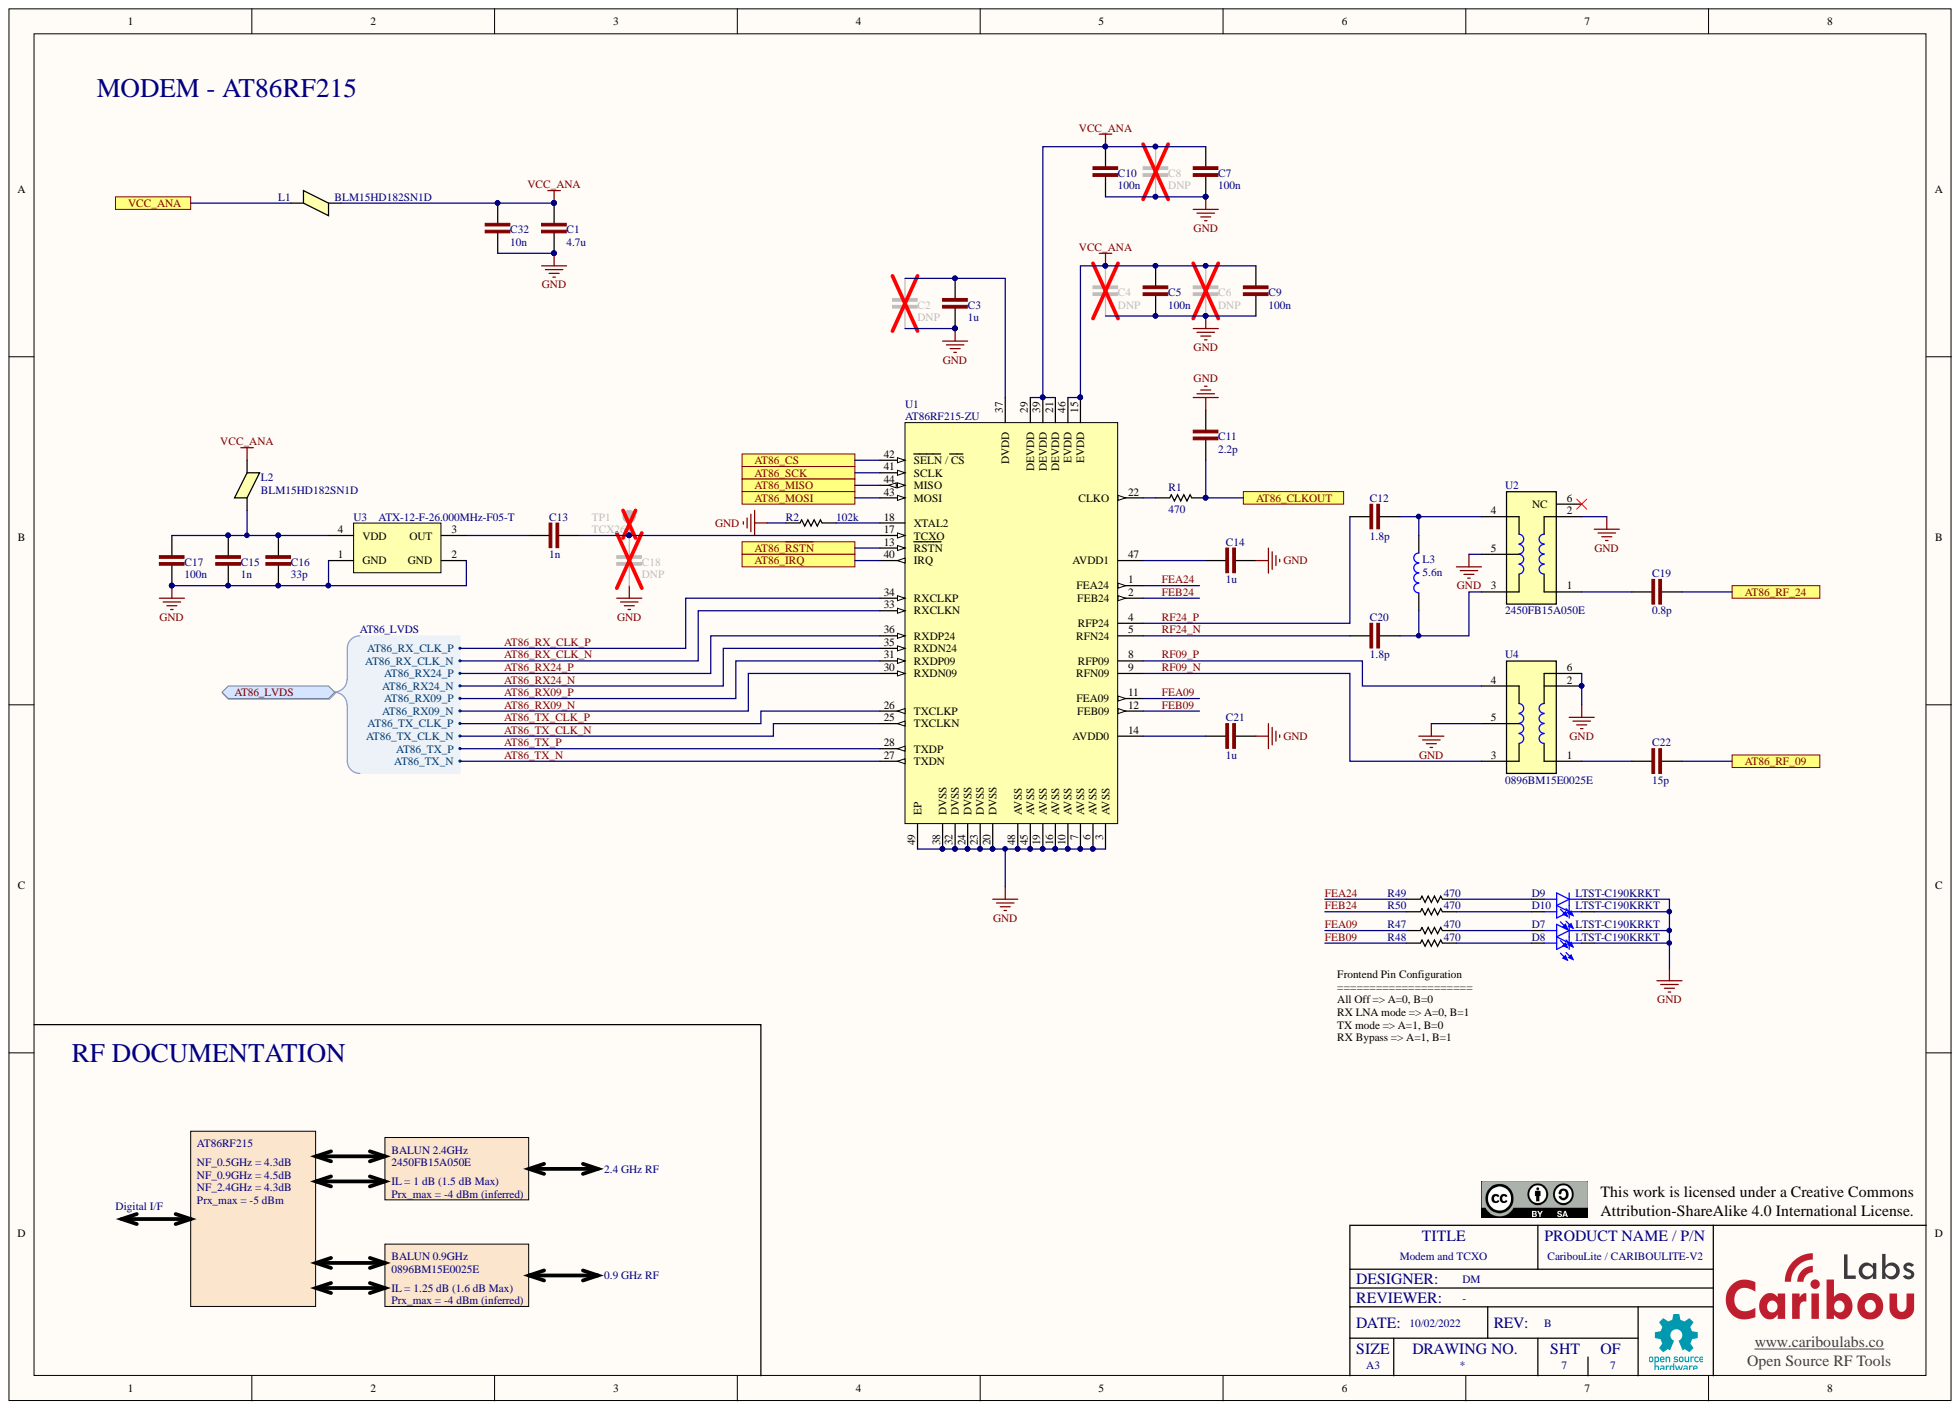
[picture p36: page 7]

RXCLKN 33

RXDP24 36

AT86_RX_CLK_P | RXDN24 35
AT86_RX_CLK_N | RXDP09 31

IL = 1 dB (1.5 dB Max)

This work is licensed under a Creative Commons
Attribution-ShareAlike 4.0 International License.

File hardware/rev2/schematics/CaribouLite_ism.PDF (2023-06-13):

SIZE; DRAWING NO.; CaribouLite / CARIBOULITE-V2; TITLE; PRODUCT NAME / P/N; Block Diagrams; POWER (LDOs); HAT EEPROM; 8BIT / 3.3V; LVDS I/Q; SMI / IRQ

RF PATH, FILTERS, AMPS

SPI / IRQ / GPIOs

LDOs
CONNECTORS / SWITCHES
DIGITAL IC
ANALOG / MIXED IC

This work is licensed under a Creative Commons
Attribution-ShareAlike 4.0 International License.

www.cariboulabs.co
Open Source RF Tools

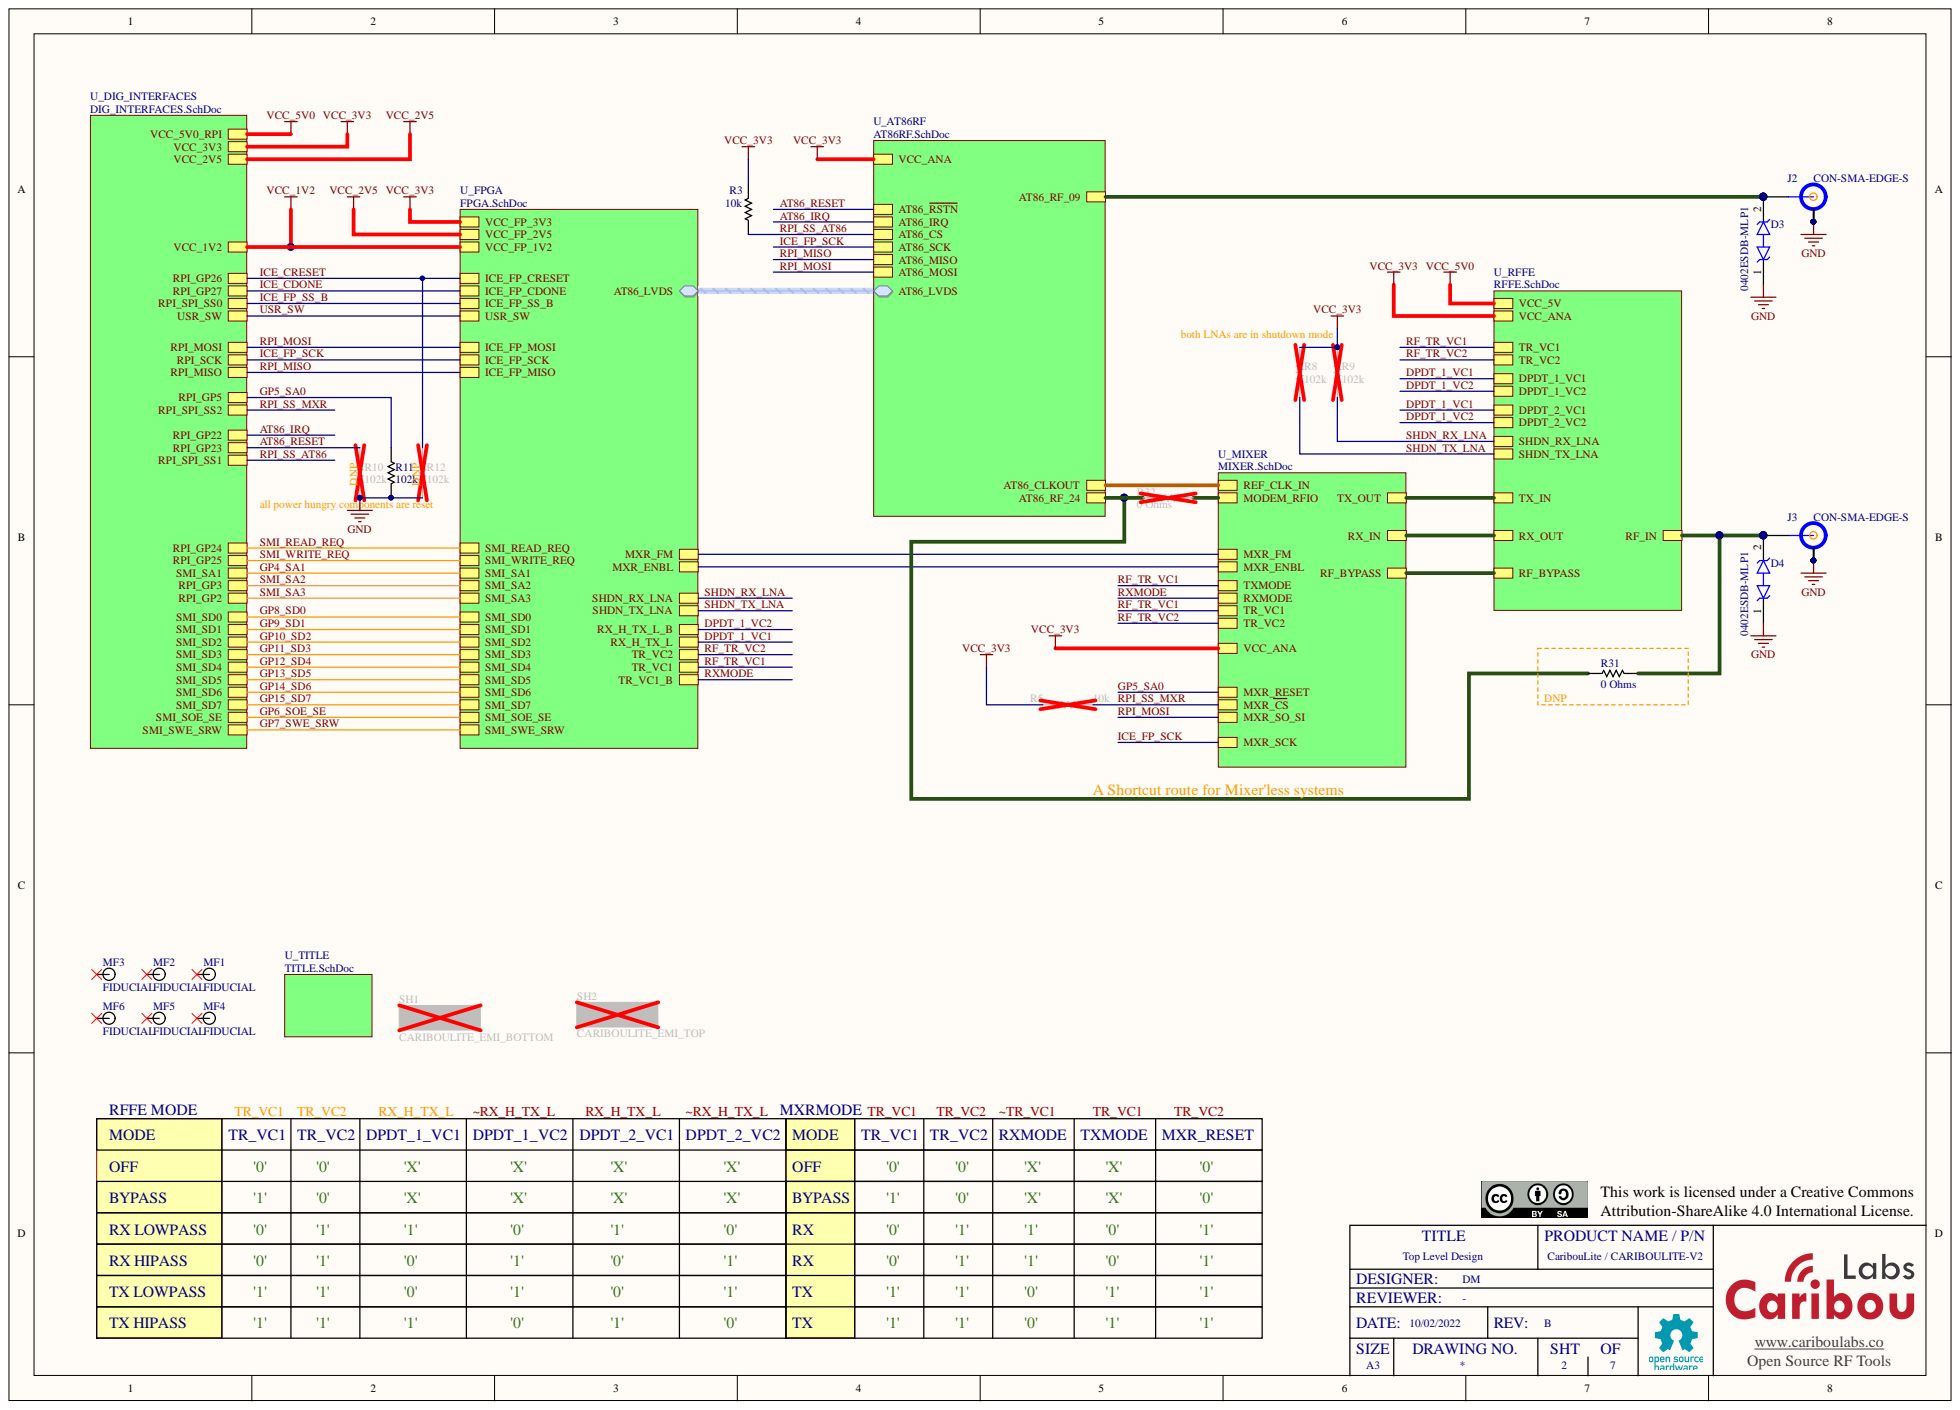
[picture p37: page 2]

I CE_F P_S S_B
US R_S W

ute for Mixer'less system

MODE | TR_VC1 | TR_VC2 | DPDT_ 1 _VC1 | DPDT_ 1 _VC2 | DPDT_ 2 _VC1 | DPDT_ 2 _VC2 | MODE | TR_VC1 | TR_VC2 | RXMODE | TXMODE | MXR_RESET

OFF | '0 ' | '0 ' | 'X' | 'X' | 'X' | 'X' | OFF | '0 ' | '0 ' | 'X' | 'X' | '0 '

This work is licensed u
Attrib

BYPASS | '1 ' | '0 ' | 'X' | 'X' | 'X' | 'X' | BYPASS | '1 ' | '0 ' | 'X' | 'X' | '0 '

RX LOWPASS | '0 ' | '1 ' | '1 ' | '0 ' | '1 ' | '0 ' | RX | '0 ' | '1 ' | '1 ' | '0 ' | '1 '

RX HIPASS | '0 ' | '1 ' | '0 ' | '1 ' | '0 ' | '1 ' | RX | '0 ' | '1 ' | '1 ' | '0 ' | '1 '

TX LOWPASS | '1 ' | '1 ' | '0 ' | '1 ' | '0 ' | '1 ' | TX | '1 ' | '1 ' | '0 ' | '1 ' | '1 '


RASPBERRY PI 40-PIN HEADER

VSS 4 | RPI_INTER_SDA
EP 9

replaced LDL212PV33R (not avaiable) by NCV8187AMT330TAG - a mess!

This work is licensed under a Creative Commons
Attribution-ShareAlike 4.0 International License.

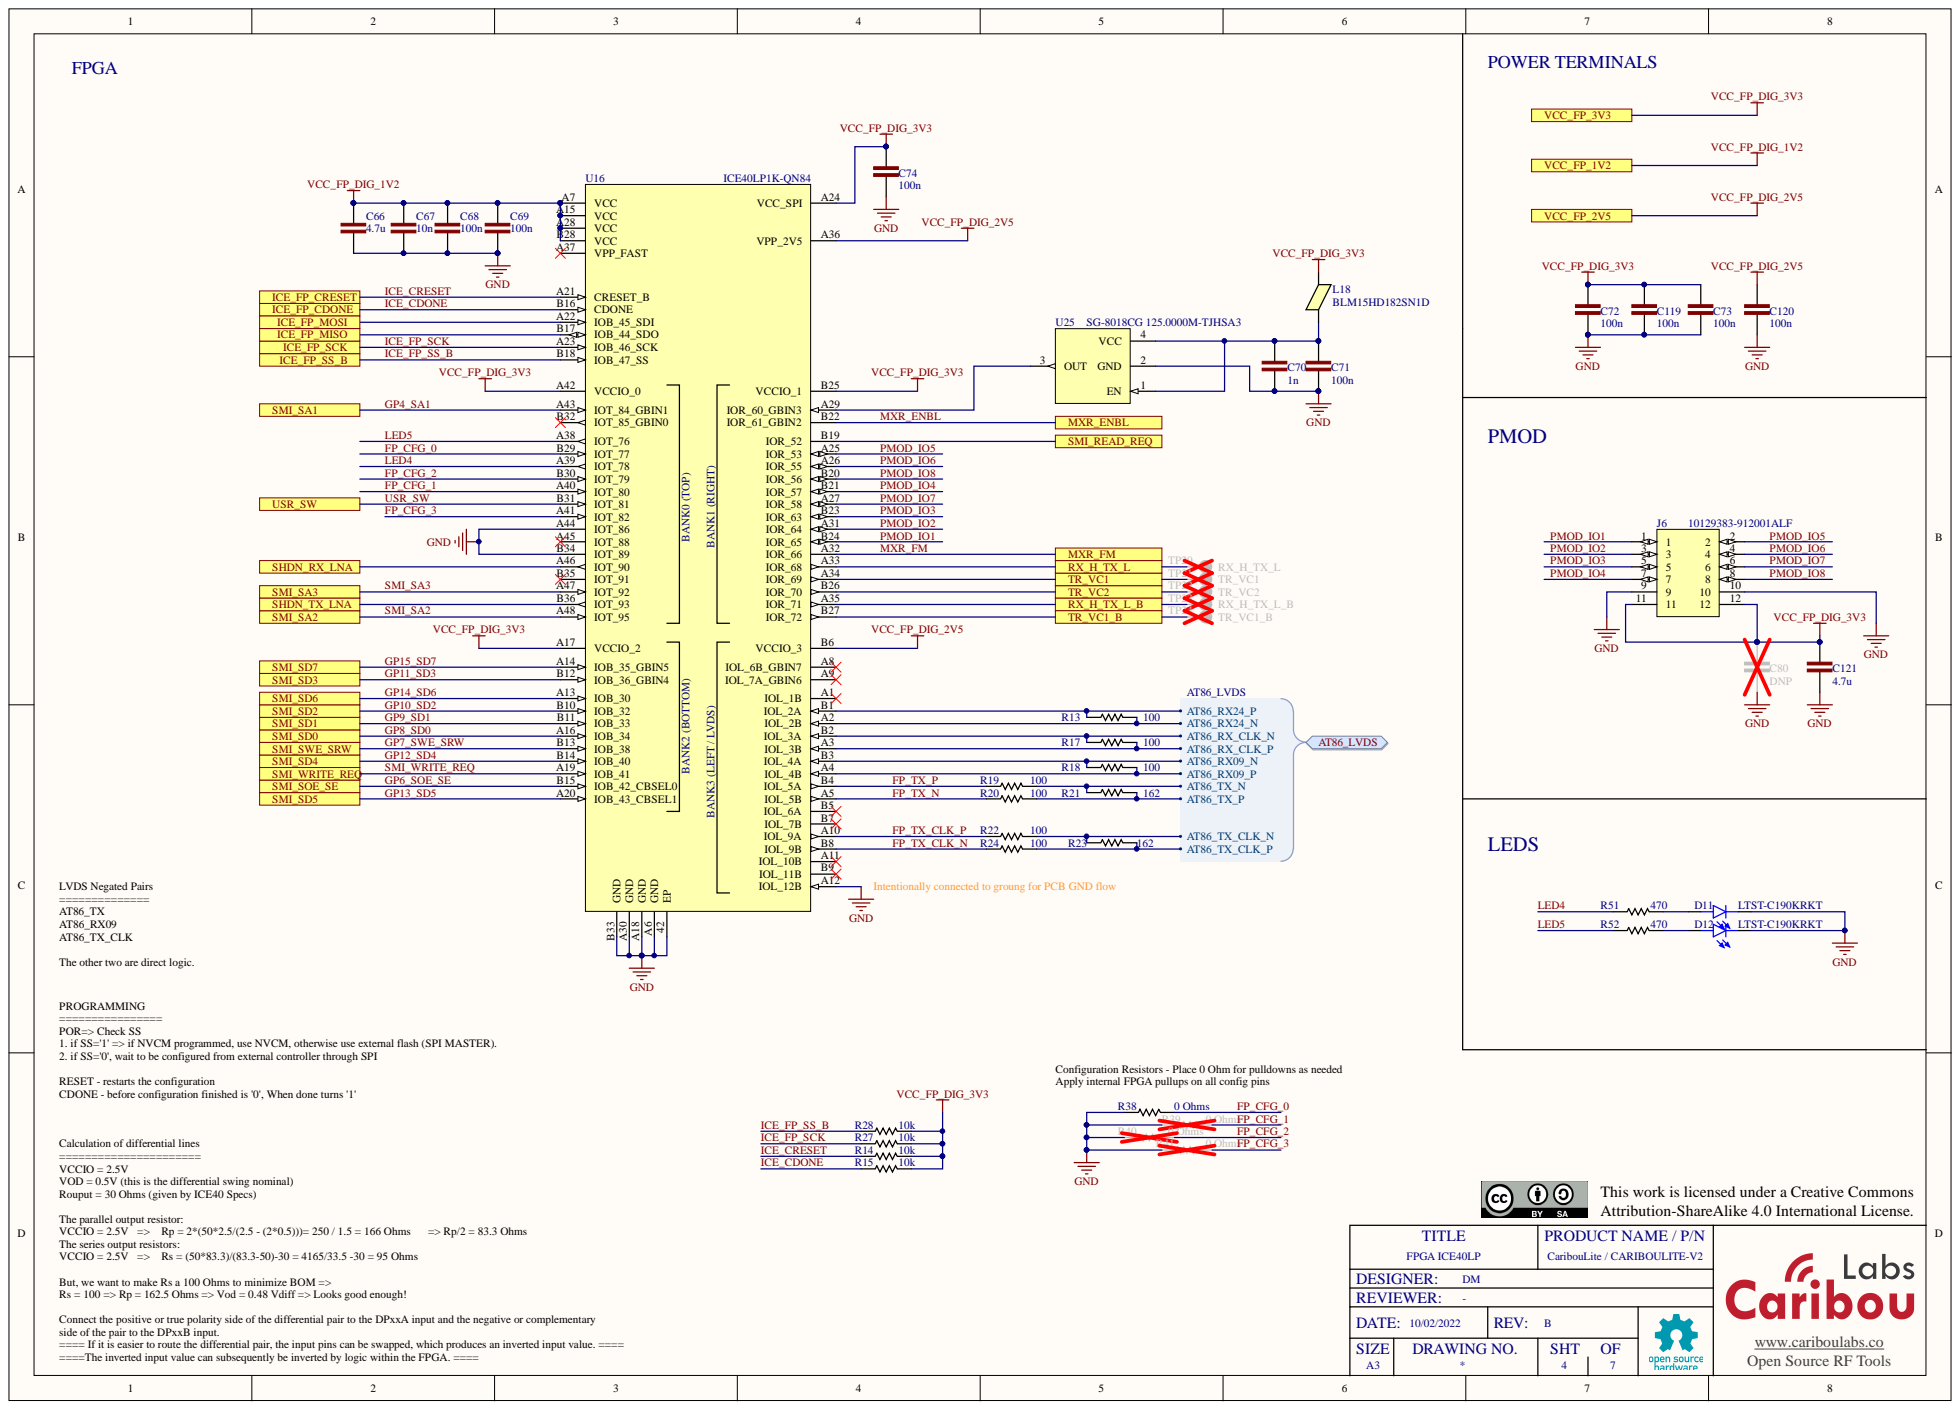
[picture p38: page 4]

EP 42 GND A6 GND A18 GND A30 GND B33

cted to groung for P

S='1' => if NVCM progr
S='0', wait to be configur

ammed, use NVCM, othe
ed from exte

esistors - Pla
PGA pullups on all config pins

e 0 Ohm for pulldowns as ne

ation
ation finished is '0', When done turns '1'

VOD = 0.5V (this is the diffe
Rouput = 30 Ohms (given by I

This work is licensed u
Attrib

But, we want to make Rs a 100 Ohms to minimiz
Rs = 100 => Rp = 162.5 Ohms => Vod = 0.48 Vdiff => Looks good enough! Connect the positive or true polarity side of the differential pair to the DPxxA input and the negative or complementa

side of the pair to the DPxxB input.
====The inve

r to route the diffe

an subsequently be inve

ential pair, the input pins c

an be swapped, which produc

rted by logic within the F

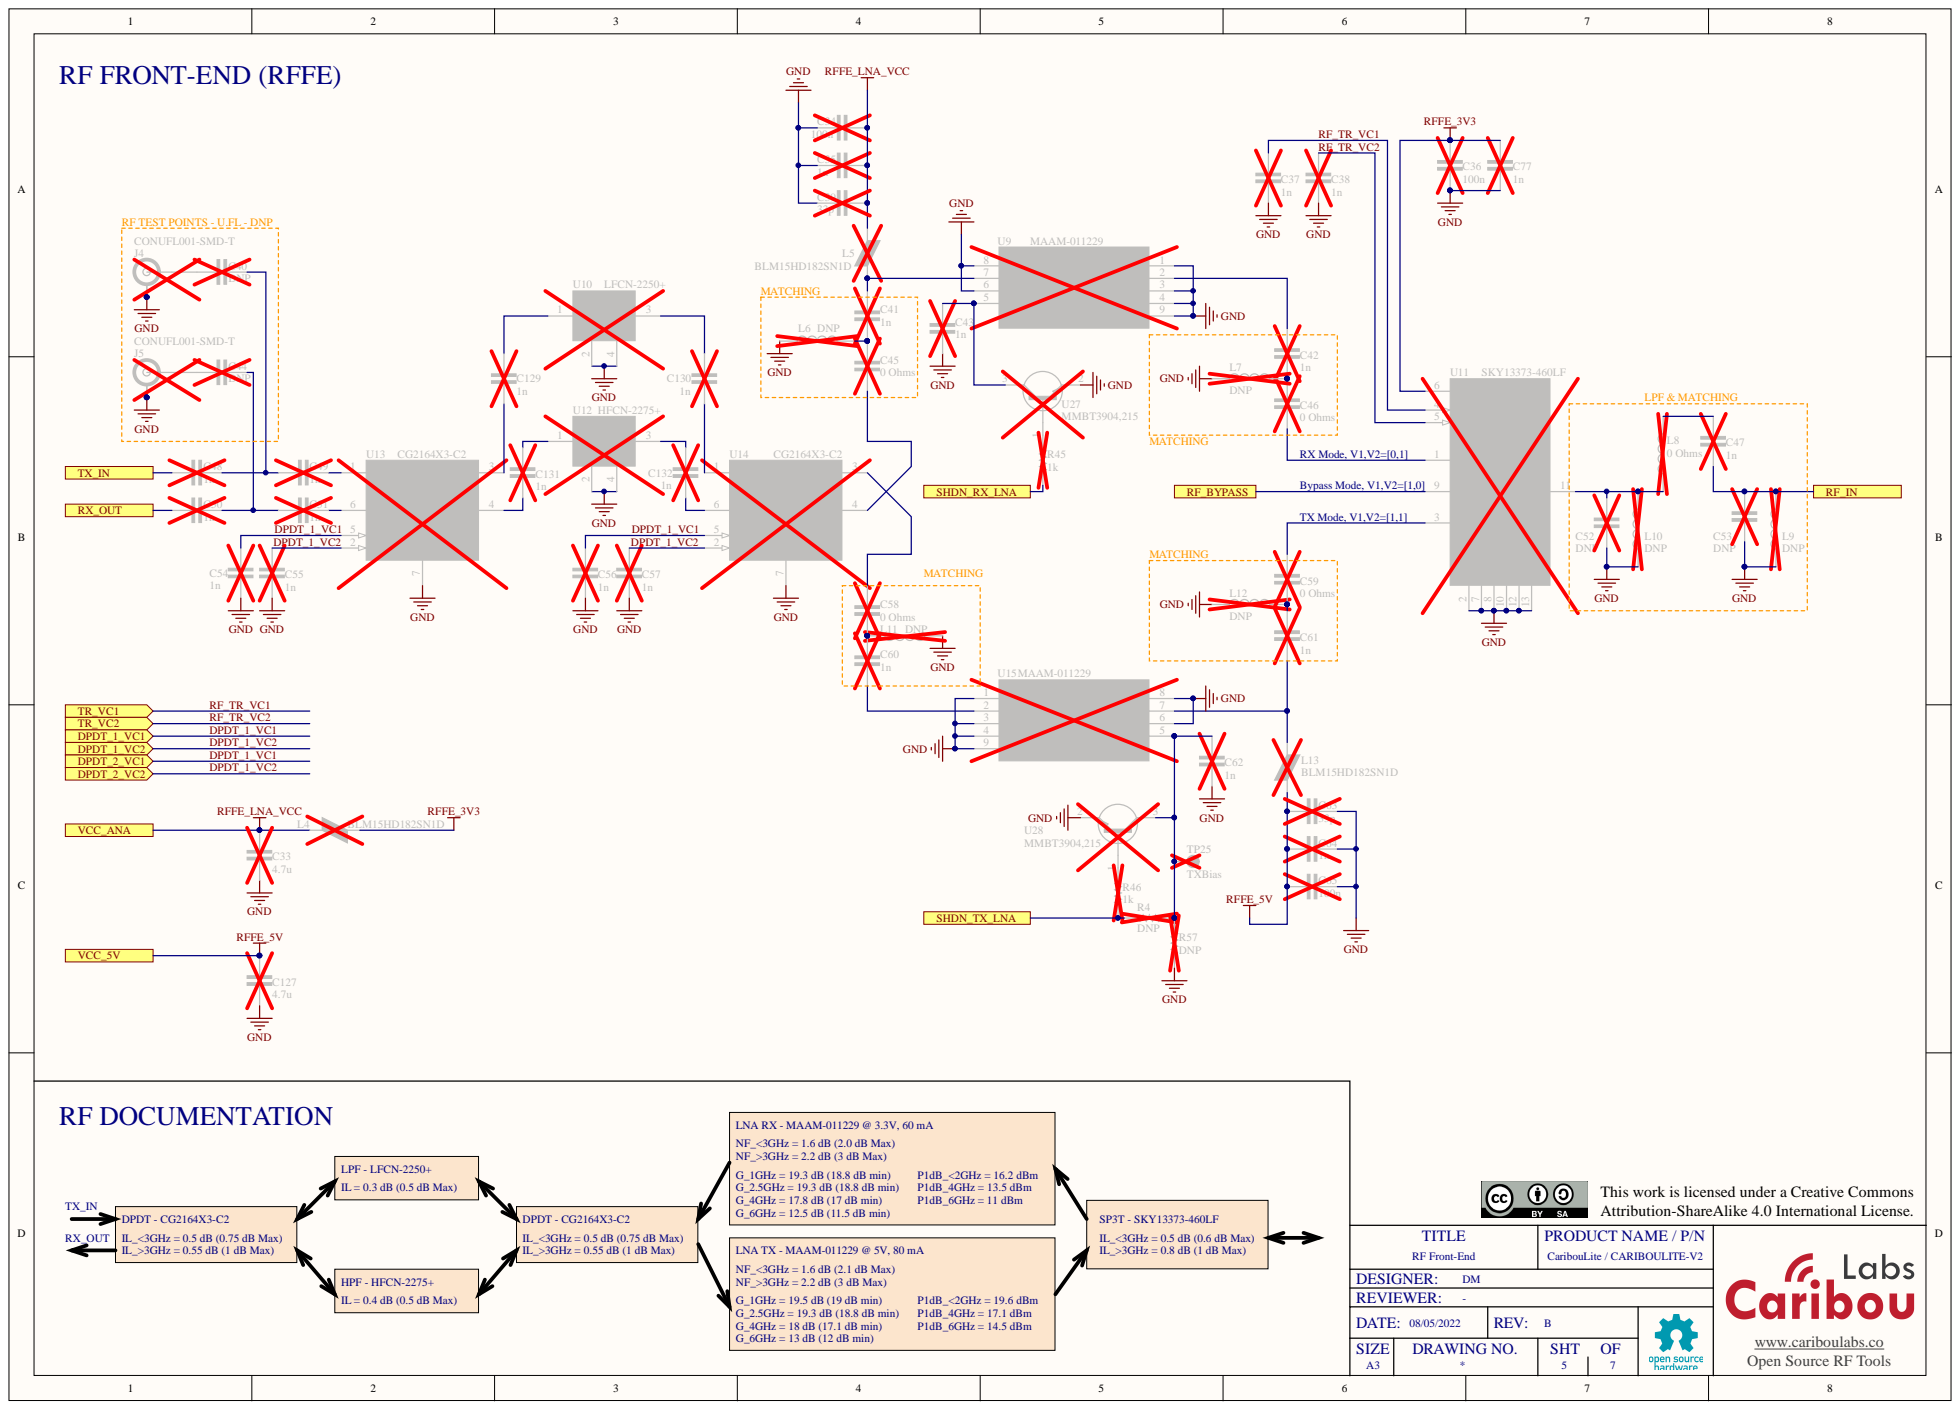
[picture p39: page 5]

RF FRONT-END (RF

RX Mode, V1,V2=[0,1] Bypass Mode, V1,V2=[1,0]

3 | PE/GND

LNA RX - MAAM-011229 @ 3.3V, 60 mA
NF_<3GHz = 1.6 dB (2.0 dB Max)
NF_>3GHz = 2.2 dB (3 dB Max)
G_1GHz = 19.3 dB (18.8 dB min)
G_2.5GHz = 19.3 dB (18.8 dB min)
G_4GHz = 17.8 dB (17 dB min)
G_6GHz = 12.5 dB (

This work is licensed u
Attrib

DPDT - CG2164X3-
IL_>3GHz = 0.55 dB (1 dB Max) IL_<3GHz = 0.5 dB (0.75 dB Max)

IL_>3GHz = 0.8 dB (1 dB Max) IL_<3GHz = 0.5 dB (0.6 dB Max)

LNA TX - MAAM-011229 @ 5V, 80 mA
NF_<3GHz = 1.6 dB (2.1 dB Max)
G_1GHz = 19.5 dB (19 dB min)
G_4GHz = 18 dB (17.1 dB min)
G_6GHz = 13 dB (12 dB min)

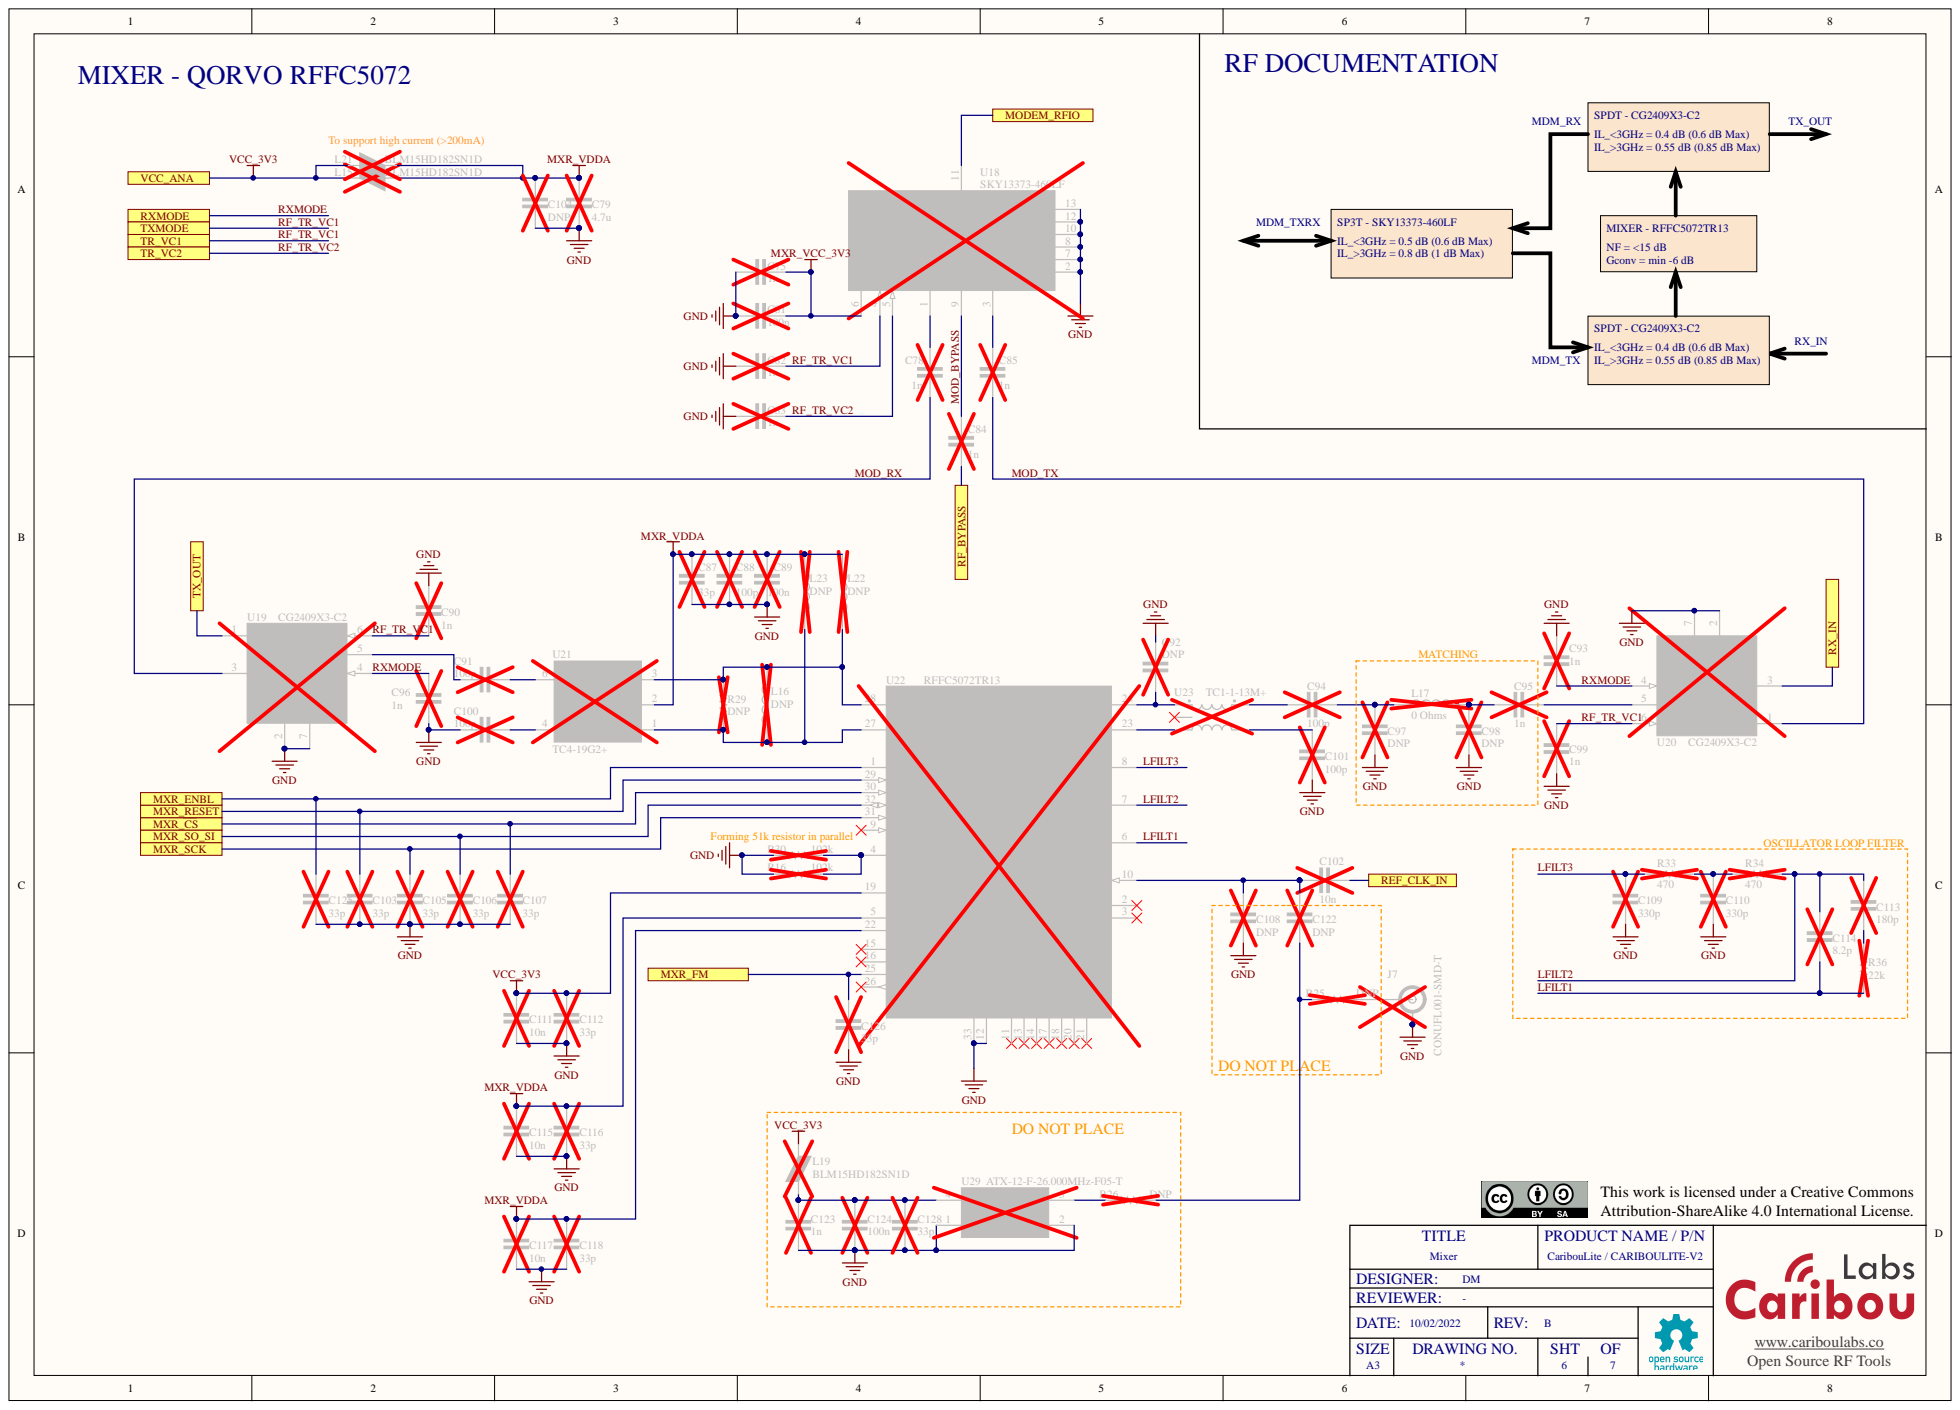
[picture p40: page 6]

RF DOCUMENTATION MIXER - QORVO RFFC5072

To support high current (>200mA)

RXMODE

GND | RESETX 29

ENX 30

MXR_ENBL | | SCLK 31 SDATA 32
MXR_RESET
MXR_CS | | | MODE/GPO6 9
MXR_SO_SI | | | | REXT 4

Forming 51k resistor in parallel

C107 33p | ANA_VDD1 5

ANA_VDD2 22

This work is licensed under a Creative Commons
Attribution-ShareAlike 4.0 International License.


RXCLKN 33

RXDP24 36

AT86_RX_CLK_P | RXDN24 35
AT86_RX_CLK_N | RXDP09 31

IL = 1 dB (1.5 dB Max)

This work is licensed under a Creative Commons
Attribution-ShareAlike 4.0 International License.

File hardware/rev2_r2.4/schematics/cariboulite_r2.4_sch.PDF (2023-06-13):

SIZE; DRAWING NO.; CaribouLite / CARIBOULITE-V2; TITLE; PRODUCT NAME / P/N; Block Diagrams; POWER (LDOs); HAT EEPROM; 8BIT / 3.3V; LVDS I/Q; SMI / IRQ; WRITE PROTECT; This work is licensed under a Creative Commons

RF PATH, FILTERS, AMPS

SPI / IRQ / GPIOs

LDOs
CONNECTORS / SWITCHES
DIGITAL IC
ANALOG / MIXED IC

Attribution-ShareAlike 4.0 International License.

www.cariboulabs.co
Open Source RF Tools


ICE_CDONE
RPI_SS_FPGA
USR_SW

both LNAs are in shutdown mode

RPI_MISO

MXR_RESET R11 102k | R12 102k

all power hungry components are reset

A Shortcut route for Mixer'less systems

MODE | TR_VC1 | TR_VC2 | DPDT_1_VC1 | DPDT_1_VC2 | DPDT_2_VC1 | DPDT_2_VC2 | MODE | TR_VC1 | TR_VC2 | RXMODE | TXMODE | MXR_RESET

OFF | '0' | '0' | 'X' | 'X' | 'X' | 'X' | OFF | '0' | '0' | 'X' | 'X' | '0'

This work is licensed under a Creative Commons
Attribution-ShareAlike 4.0 International License.

BYPASS | '1' | '0' | 'X' | 'X' | 'X' | 'X' | BYPASS | '1' | '0' | 'X' | 'X' | '0'

RX LOWPASS | '0' | '1' | '1' | '0' | '1' | '0' | RX | '0' | '1' | '1' | '0' | '1'

RX HIPASS | '0' | '1' | '0' | '1' | '0' | '1' | RX | '0' | '1' | '1' | '0' | '1'

TX LOWPASS | '1' | '1' | '0' | '1' | '0' | '1' | TX | '1' | '1' | '0' | '1' | '1'


RASPBERRY PI 40-PIN HEADER

NOTE: Dual function - WP for HAT EEPROM

A2 3
VSS 4 | RPI_INTER_SDA
EP 9

ND 1 ADJ/SENSE 2 VOUT 3

This work is licensed under a Creative Commons
Attribution-ShareAlike 4.0 International License.


Intentionally connected to groung for PCB GND flow

The other two are direct logic.

PROGRAMMING
POR=> Check SS
1. if SS='1' => if NVCM programmed, use NVCM, otherwise use external flash (SPI MASTER).
2. if SS='0', wait to be configured from external controller through SPI

Configuration Resistors - Place 10k for pulldown as needed
Apply internal FPGA pullups on all config pins

RESET - restarts the configuration
CDONE - before configuration finished is '0', When done turns '1'

Calculation of differential lines
VCCIO = 2.5V
VOD = 0.5V (this is the differential swing nominal)
Rouput = 30 Ohms (given by ICE40 Specs)

This work is licensed under a Creative Commons
Attribution-ShareAlike 4.0 International License.

The parallel output resistor:
The series output resistors:
VCCIO = 2.5V => Rs = (50*83.3)/(83.3-50)-30 = 4165/33.5 -30 = 95 Ohms

But, we want to make Rs a 100 Ohms to minimize BOM =>
Rs = 100 => Rp = 162.5 Ohms => Vod = 0.48 Vdiff => Looks good enough!

Connect the positive or true polarity side of the differential pair to the DPxxA input and the negative or complementary
side of the pair to the DPxxB input.
==== If it is easier to route the differential pair, the input pins can be swapped, which produces an inverted input value. ====
====The inverted input value can subsequently be inverted by logic within the FPGA. ====


RF FRONT-END (RFFE)

NC 3

LNA RX - MAAM-011229 @ 3.3V, 60 mA
NF_<3GHz = 1.6 dB (2.0 dB Max)
NF_>3GHz = 2.2 dB (3 dB Max)
G_1GHz = 19.3 dB (18.8 dB min)
G_2.5GHz = 19.3 dB (18.8 dB min)
G_4GHz = 17.8 dB (17 dB min)
G_6GHz = 12.5 dB (11.5 dB min)

LPF - LFCN-2250+
IL = 0.3 dB (0.5 dB Max)

This work is licensed under a Creative Commons
Attribution-ShareAlike 4.0 International License.

LNA TX - MAAM-011229 @ 5V, 80 mA
NF_<3GHz = 1.6 dB (2.1 dB Max)
G_1GHz = 19.5 dB (19 dB min)
G_4GHz = 18 dB (17.1 dB min)
G_6GHz = 13 dB (12 dB min)

HPF - HFCN-2275+
IL = 0.4 dB (0.5 dB Max)


RF DOCUMENTATION MIXER - QORVO RFFC5072

To support high current (>200mA)

RXMODE

DNP 2 | U22

GND | RESETX 29

ENX 30

MXR_ENBL | | SCLK 31 SDATA 32
MXR_RESET
MXR_CS | | | MODE/GPO6 9
MXR_SO_SI | | | | REXT 4

Forming 51k resistor in parallel

C107 33p | ANA_VDD1 5

ANA_VDD2 22

This work is licensed under a Creative Commons
Attribution-ShareAlike 4.0 International License.


RXCLKN 33

RXDP24 36

AT86_RX_CLK_P | RXDN24 35
AT86_RX_CLK_N | RXDP09 31

IL = 1 dB (1.5 dB Max)

This work is licensed under a Creative Commons
Attribution-ShareAlike 4.0 International License.

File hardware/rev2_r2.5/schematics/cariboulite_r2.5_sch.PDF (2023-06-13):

SIZE; DRAWING NO.; CaribouLite / CARIBOULITE-V2; TITLE; PRODUCT NAME / P/N; Block Diagrams; POWER (LDOs); HAT EEPROM; 8BIT / 3.3V; LVDS I/Q; SMI / IRQ

RF PATH, FILTERS, AMPS

SPI / IRQ / GPIOs

LDOs
CONNECTORS / SWITCHES
DIGITAL IC
ANALOG / MIXED IC

This work is licensed under a Creative Commons
Attribution-ShareAlike 4.0 International License.

www.cariboulabs.co
Open Source RF Tools


R P I_S S_F PGA
US R_S W

ute for Mixer'less system

MODE | TR_VC1 | TR_VC2 | DPDT_ 1 _VC1 | DPDT_ 1 _VC2 | DPDT_ 2 _VC1 | DPDT_ 2 _VC2 | MODE | TR_VC1 | TR_VC2 | RXMODE | TXMODE | MXR_RESET

OFF | '0 ' | '0 ' | 'X' | 'X' | 'X' | 'X' | OFF | '0 ' | '0 ' | 'X' | 'X' | '0 '

This work is licensed u
Attrib

BYPASS | '1 ' | '0 ' | 'X' | 'X' | 'X' | 'X' | BYPASS | '1 ' | '0 ' | 'X' | 'X' | '0 '

RX LOWPASS | '0 ' | '1 ' | '1 ' | '0 ' | '1 ' | '0 ' | RX | '0 ' | '1 ' | '1 ' | '0 ' | '1 '

RX HIPASS | '0 ' | '1 ' | '0 ' | '1 ' | '0 ' | '1 ' | RX | '0 ' | '1 ' | '1 ' | '0 ' | '1 '

annot open file
rs\David\Dropbox\Dropbox\C

TX LOWPASS | '1 ' | '1 ' | '0 ' | '1 ' | '0 ' | '1 ' | TX | '1 ' | '1 ' | '0 ' | '1 ' | '1 '


RASPBERRY PI 40-PIN HEADER

VSS 4 | RPI_INTER_SDA
EP 9

ND 1 ADJ/SENSE 2 VOUT 3

This work is licensed under a Creative Commons
Attribution-ShareAlike 4.0 International License.


Intentionally connected to groung for PCB GND flow

The other two are direct logic.

PROGRAMMING
POR=> Check SS
1. if SS='1' => if NVCM programmed, use NVCM, otherwise use external flash (SPI MASTER).
2. if SS='0', wait to be configured from external controller through SPI

Configuration Resistors - Place 0 Ohm for pulldowns as needed
Apply internal FPGA pullups on all config pins

RESET - restarts the configuration
CDONE - before configuration finished is '0', When done turns '1'

Calculation of differential lines
VCCIO = 2.5V
VOD = 0.5V (this is the differential swing nominal)
Rouput = 30 Ohms (given by ICE40 Specs)

This work is licensed under a Creative Commons
Attribution-ShareAlike 4.0 International License.

The parallel output resistor:
The series output resistors:
VCCIO = 2.5V => Rs = (50*83.3)/(83.3-50)-30 = 4165/33.5 -30 = 95 Ohms

But, we want to make Rs a 100 Ohms to minimize BOM =>
Rs = 100 => Rp = 162.5 Ohms => Vod = 0.48 Vdiff => Looks good enough!

Connect the positive or true polarity side of the differential pair to the DPxxA input and the negative or complementary
side of the pair to the DPxxB input.
==== If it is easier to route the differential pair, the input pins can be swapped, which produces an inverted input value. ====
====The inverted input value can subsequently be inverted by logic within the FPGA. ====


RF FRONT-END (RF

RX Mode, V1,V2=[0,1] Bypass Mode, V1,V2=[1,0]

3 | PE/GND

LNA RX - MAAM-011229 @ 3.3V, 60 mA
NF_<3GHz = 1.6 dB (2.0 dB Max)
NF_>3GHz = 2.2 dB (3 dB Max)
G_1GHz = 19.3 dB (18.8 dB min)
G_2.5GHz = 19.3 dB (18.8 dB min)
G_4GHz = 17.8 dB (17 dB min)
G_6GHz = 12.5 dB (

This work is licensed u
Attrib

DPDT - CG2164X3-
IL_>3GHz = 0.55 dB (1 dB Max) IL_<3GHz = 0.5 dB (0.75 dB Max)

IL_>3GHz = 0.8 dB (1 dB Max) IL_<3GHz = 0.5 dB (0.6 dB Max)

LNA TX - MAAM-011229 @ 5V, 80 mA
NF_<3GHz = 1.6 dB (2.1 dB Max)
G_1GHz = 19.5 dB (19 dB min)
G_4GHz = 18 dB (17.1 dB min)
G_6GHz = 13 dB (12 dB min)


RF DOCUMENTATION MIXER - QORVO RFFC5072

To support high current (>200mA)

RXMODE

GND | RESETX 29

ENX 30

MXR_ENBL | | SCLK 31 SDATA 32
MXR_RESET
MXR_CS | | | MODE/GPO6 9
MXR_SO_SI | | | | REXT 4

Forming 51k resistor in parallel

C107 33p | ANA_VDD1 5

ANA_VDD2 22

This work is licensed under a Creative Commons
Attribution-ShareAlike 4.0 International License.


RXCLKN 33

RXDP24 36

AT86_RX_CLK_P | RXDN24 35
AT86_RX_CLK_N | RXDP09 31

IL = 1 dB (1.5 dB Max)

This work is licensed under a Creative Commons
Attribution-ShareAlike 4.0 International License.

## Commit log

2023-06-13 first commit
    moving all hardware files to this repository to separate and reduce the main repo
    [HFCN.csv, bom.xlsx, bottom_emi_drawing.dxf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]
2024-01-10 added hardwate circuit studio sources
    [AT86RF.SchDoc, CaribouLite.PrjPcb, DIG_INTERFACES.SchDoc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]
